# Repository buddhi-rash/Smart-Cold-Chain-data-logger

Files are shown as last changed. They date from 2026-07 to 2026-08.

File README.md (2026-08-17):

# Smart Cold-Chain Data Logger

A rechargeable, multi-use, cellular-connected temperature and humidity logger for pharmaceutical cold-chain monitoring.  
Designed to solve the **$35 billion annual spoilage problem** by providing real-time alerts, ±0.1 °C accuracy, and direct USB‑C PDF/CSV export—without proprietary software or cloud lock-in.

---

## 🔍 Problem

Cold‑chain failures in pharmaceuticals and biologics lead to massive product loss and regulatory risk. Existing loggers are either passive (USB‑only, no real‑time visibility) or expensive real‑time trackers locked into proprietary platforms. This project delivers an **open, rechargeable, and accurate** alternative.

---

## ✨ Key Features

- **±0.1 °C accuracy** (Sensirion SHT45) for GDP/regulatory compliance  
- **Real‑time LTE‑M/NB‑IoT alerts** via SIM7070G / A7670C cellular module  
- **30‑day battery life** (5000 mAh 21700 Li‑Ion, ultra‑low‑power design)  
- **USB‑C mass‑storage export** – plug into any PC, get PDF + CSV automatically  
- **Condition‑based monitoring** – logging frequency adapts near alarm thresholds  
- **External PT100 RTD probe** support for payload‑core temperature  
- **Minimalistic UI** – 1.3″ OLED, 3 tactile buttons, RGB status LED, piezo buzzer  
- **HTTPS cloud** – Cloud upload the data in real time  
- **4‑layer PCB** with controlled impedance (90 Ω USB), hand‑solderable components  

---

## 🧰 Repository Structure

---

## 🔧 Hardware Overview

| Subsystem | Component | Notes |
|---|---|---|
| MCU | STM32L412CBT6 (Cortex‑M4, 80 MHz) | Ultra‑low‑power Stop 2 mode (0.7 µA) |
| Temperature/Humidity | Sensirion SHT45 (or SHT40) | ±0.1 °C typical |
| External RTD | MAX31865 + PT100 probe | 3‑wire, –200 to +200 °C |
| Cellular | SIM7070G HAT/ A7670C | LTE‑M/NB‑IoT, 2G fallback, GNSS |
| Storage | W25Q128/W25R128 16 MB SPI flash | ~800,000 records |
| Fuel Gauge | MAX17048 | ModelGauge, 4 µA hibernate |
| Light / Motion | OPT3001, LIS3DH | Door‑open detection, tilt/shock |
| Display | 1.3″ OLED (I²C) | 128×64, industrial temp |
| Power | MCP73831 charger, TPS631000 buck‑boost, S‑8211CAH protection | Load‑sharing circuit for USB operation |
| Battery | 21700 Li‑Ion 5000 mAh | 60‑day runtime with condition‑based monitoring |

The PCB is a **4‑layer S‑G‑P‑S** stackup (JLCPCB JLC04161H‑7628) with controlled impedance for USB. All components are hand‑solderable (LQFP, SOIC, SOT, 0603).

---

## 📟 Firmware Overview

Written in **C** using STM32 HAL and FreeRTOS (optional). Key modules:

- **Sensor drivers** – I²C/SPI for all sensors, with interrupt‑driven wake‑up.
- **Power manager** – Stop 2 mode scheduling, RTC wake‑up, condition‑based logging.
- **Modem manager** – AT command parser, MQTT publisher (TLS), PSM control.
- **USB MSC** – TinyUSB + FatFS for PDF/CSV generation on the fly.
- **UI manager** – 3‑button menu state machine, OLED rendering, RGB LED control.

Build with **STM32CubeIDE**; project file located in `/firmware/core`.

---

## 🚀 Getting Started

### Prerequisites
- STM32CubeIDE, ST‑LINK programmer
- IoT SIM card (1.8 V, LTE‑M/NB‑IoT)
- USB‑C cable
- Li‑Ion 18650 cell

### Flashing
1. Connect ST‑LINK to the SWD header.
2. Open the project in STM32CubeIDE.
3. Build and flash the firmware.

### First Power‑Up
1. Insert the IoT SIM card (observing orientation).
2. Charge the battery via USB‑C (about 10 hours full).
3. Press **MENU** to power on and navigate the UI.
4. Configure logging interval, upload interval, and alarm thresholds.
5. Mount the logger in the shipment; data will upload automatically.

### Data Retrieval
- Plug the logger into any PC via USB‑C. It appears as a mass‑storage drive.
- Copy `TRIP_REPORT.PDF` and `TRIP_DATA.CSV`.

---

## 📄 Documentation

Detailed documents are in the `docs/` folder:
- `architecture.md` – full block diagram and pin mapping.
- `user-manual.md` – complete user guide.
- `testing.md` – power consumption measurements, validation results.

---

## 🧪 Testing & Validation

- **24‑hour current profile:** average 8.4 mA (10‑min logging, 2‑hr upload) → ~20 days worst‑case, 60 days with condition‑based monitoring.
- **Sensor accuracy:** verified against reference thermometer in climate chamber.
- **Cellular reliability:** 100% registration on A7670C (SIM7070G had intermittent failures – see note in docs).
- **USB export:** PDF/CSV generation tested on Windows, macOS, Linux.

---

## 📜 License

This project is licensed under the **MIT License** – see the `LICENSE` file for details.

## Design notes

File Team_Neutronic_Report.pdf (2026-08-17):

Real-Time Data Logger for Global Transportation — Team Neutronic

### T E A M N E U T R O N I C

# Real-Time Data Logger for Global Transportation

### Project Report · Version 1.0

Prepared by
Kumara K.B.R. — 230352 K
Kumara P.K.M.P. — 230353 N Jayaweera N.S. — 230300 C
Gunarathna K.T.M.B. — 230203 G Ranawaka R.A.G.K. — 230527 D

Department of Electronic and Telecommunication Engineering University of Moratuwa, Sri Lanka

13 July 2026

## Table of Contents

## 1. Introduction

## 1.1 Project Overview

Problem Statement

The global cold-chain logistics industry, particularly the pharmaceutical and biologics sector, faces a critical challenge: temperature excursions during transport and storage cause an estimated $35 billion in annual product spoilage, with a single cold-chain failure potentially costing an organisation up to $95 million in medical inventory. Regulatory frameworks such as Good Distribution Practice (GDP) mandate continuous, accurate temperature monitoring with traceable calibration, yet 92% of supply-chain professionals admit they cannot fully trust their logistics data.

Existing cold-chain monitoring solutions fall into two unsatisfactory categories:

- Passive USB-only data loggers (e.g., Testo 175-T2, Elitech RC-5+): record temperature locally but provide no real-time visibility. Excursions are only discovered after delivery, when intervention is impossible — essentially “post-mortem” tools.
- Proprietary real-time trackers (e.g., Sensitech TempTale GEO, Onset CX1003): offer cellular connectivity but are typically single-use (creating electronic waste and recurring purchase costs), lock users into expensive proprietary cloud platforms, and often have limited accuracy (±0.3°C to ±0.5°C).

Our Solution

A multi-sensor, cellular-connected logger combining high accuracy, real-time alerts, USB-C data export, and an external probe bridges the gap between cheap passive tags and expensive real-time trackers — cutting spoilage and compliance risk.

## 1.2 Motivation

1. Regulatory Pressure: Good Distribution Practice (GDP) and 21 CFR Part 11 mandate continuous, accurate temperature monitoring with traceable calibration. The latest GDP revisions require real-time monitoring capability for high-value pharmaceuticals.
2. Market Demand: The global cold-chain monitoring market is projected to grow from $7.2 billion (2025) to $22.2 billion (2035) at a 12.1% CAGR. The tracking and monitoring segment alone is expected to reach $15.04 billion by 2030.
3. Local Industry Survey Evidence: A structured survey of professionals across pharmaceutical import and distribution companies in Sri Lanka confirmed the need identified above.

To validate the identified operational challenges, a targeted local survey was conducted among key healthcare stakeholders, including retail and hospital pharmacists, medical officers, and hospital administration officials.

## Survey Results

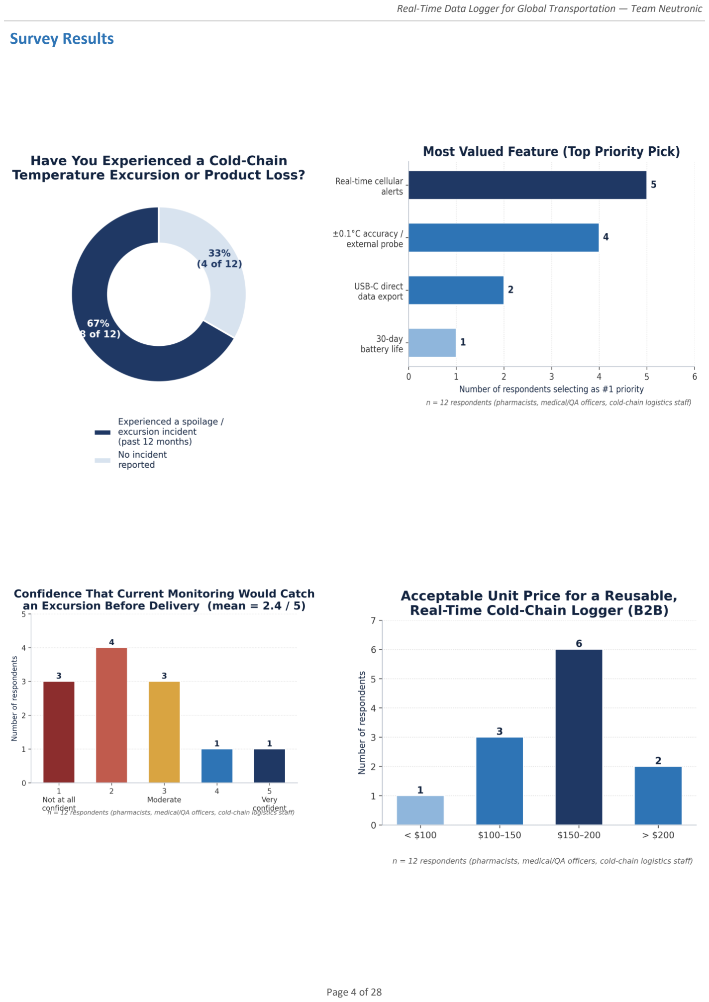
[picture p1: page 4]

## 1.3 Objectives

Primary Objective

Develop a reliable and scalable product to monitor temperature, humidity, acceleration, and optical light intensity of a global shipping delivery, logging information to local memory and uploading to a cloud database in real time.

Secondary Objectives
- 30 days of operating time on a single charge
- Global coverage for data upload
- User-configurable logging and upload intervals
- Local data access as a CSV file via mass-storage device
- Interrupt-based alarming system for critical changes in readings

## 2. Product Overview

## 2.1 Features

# | Feature | Specification

1 | Temperature Accuracy | ±0.1°C (RTD sensor)
2 | Humidity Accuracy | ±1.0% RH (SHT45)
3 | External Probe | PT100 RTD via MAX31865 (−200°C to +200°C)
4 | Connectivity | LTE-M / NB-IoT (SIM7070G HAT), 2G fallback
5 | Battery | 5000 mAh 21700 Li-Ion, rechargeable, 30-day runtime
6 | Data Export | USB-C mass-storage (auto-generated PDF/CSV), no drivers
7 | Cloud Protocol | HTTP over TLS, open platform
8 | Sensors | Light (OPT3001, door-open detection); accelerometer (LIS3DH, tilt/shock); fuel gauge (MAX17048)
9 | User Interface | 1.3″ OLED display, 3 user buttons, buzzer
10 | Enclosure | IP65, ABS, magnetic mounting, 85 × 65 × 25 mm

## 2.2 Technical Feasibility

### 2.2.1 Resource Requirements

Resource | Requirement | Availability | Status
Microcontroller | Ultra-low-power, USB 2.0, ≥128 KB Flash | STM32L412CBT6 (LQFP-48) — LCSC, DigiKey | ✅ Confirmed

Resource | Requirement | Availability | Status
Temperature/Humidity Sensor | ±0.1°C accuracy, I²C, industrial range | Sensirion SHT45-AD1B-R2 | ✅ Confirmed (SHT40-AD1F-R2 backup)
Cellular Module | LTE-M/NB-IoT, global bands, low-power PSM | Waveshare SIM7070G HAT | ✅ Confirmed

External RTD Front-end

SPI, PT100 support, industrial temp

MAX31865AAP+ (SSOP-20) | ✅ Confirmed

Memory

16 MB SPI NOR flash, >100k write cycles

Winbond W25Q128JVSIQ (SOIC-8)

Switched to W25R128JVSIQ
(availability)

Battery

≥5000 mAh, rechargeable,
single cell | Samsung 50E 21700 (5000 mAh) | Switched to 3600 mAh 18650
| | (availability)
Other Sensors | Ambient light; accelerometer;
fuel gauge | TI OPT3001; ST LIS3DHTR;
| MAX17048 | ✅ Confirmed

Power

High-efficiency regulation,
charging, protection, load sharing

TPS630001 buck-boost;
MCP73831 charger; S-8211CAH+FS8205A protection; DMP1045U MOSFET

✅ Confirmed

PCB Fabrication | 4-layer, controlled impedance (90Ω USB) | JLCPCB (JLC04161H-7628
stackup) | ✅ Confirmed
Development Tools | IDE, debugger, test equipment | STM32CubeIDE, ST-LINK V2,
oscilloscope | ✅ Confirmed

Technical Feasibility Confirmation

The project is determined to be technically feasible. All critical components are commercially available from multiple suppliers (LCSC, DigiKey), ensuring supply-chain resilience.

- The STM32L412CBT6 microcontroller meets the ultra-low-power (deep-sleep modes) and USB 2.0 requirements.
- The SIM7070G HAT eliminates complex RF design by providing a pre-certified cellular solution.
- A 24-hour current measurement confirmed an average draw of 12.4 mA (initial, unconfigured), corresponding to a 12-day worst-case battery life; with configured deep-sleep modes, ~30 days of operation is achievable.
- The PT100 sensor was validated against a calibrated reference thermometer in a climate chamber, achieving the specified ±0.1°C accuracy.
- USB mass-storage enumeration and PDF generation were successful.

In summary, all resource requirements can be met, all performance targets are reachable, and the identified risks have viable mitigations — confirming the project is ready to proceed to detailed design and prototyping.

## 2.3 System Components

The Smart Cold-Chain Data Logger integrates the following major subsystems:

- Sensing Board: SHT45, OPT3001, LIS3DH, MAX17048 on a shared I²C bus; MAX31865 on SPI.

- MCU Board: STM32L412CBT6 (Cortex-M4, 80 MHz) with external 32.768 kHz crystal for RTC.
- Storage: 16 MB SPI NOR flash (W25Q128).
- Communication: SIM7070G HAT (UART), USB-C for power and data.
- Power Management: MCP73831 charger, TPS631000 buck-boost, S-8211CAH battery protection, load-sharing circuit (DMP1045U MOSFET).
- User Interface: 1.3″ OLED (I²C), user buttons, piezo buzzer.

A block diagram appears in Section 3.1.

## 2.4 Methodology and Technology

Layer | Technology
1. Microcontroller Firmware | C, STM32CubeIDE, HAL libraries
2. Cloud Backup | HTTP over TLS (TLS 1.2); Node-RED / InfluxDB for dashboard (prototype)
3. Data Export | USB MSC (FatFS); PDF generation (embedded library); CSV
4. PCB Design | Altium Designer, WeBench Simulation; 4-layer impedance-controlled stackup (JLC04161H-7628)
5. Enclosure | SolidWorks; 3D-printed ABS

## 3. System Architecture

## 3.1 Overall System Architecture

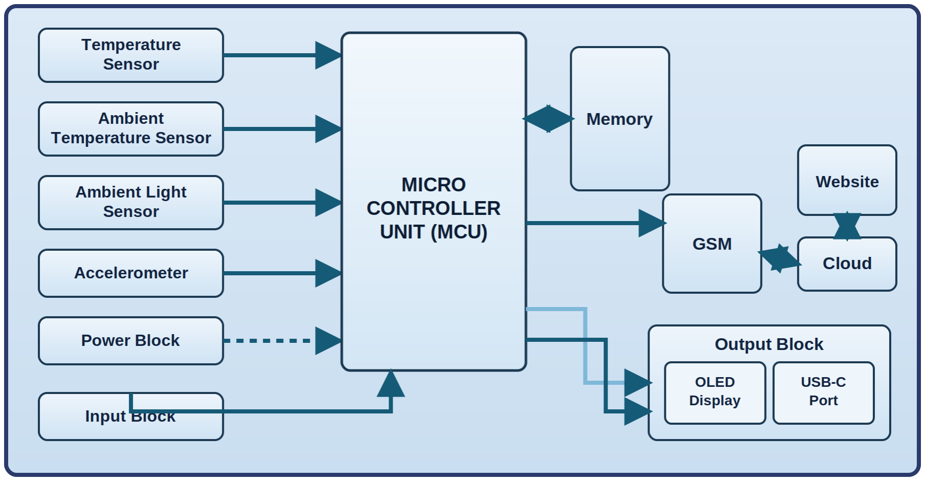
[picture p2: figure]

## 3.2 Detailed Full Block Diagram

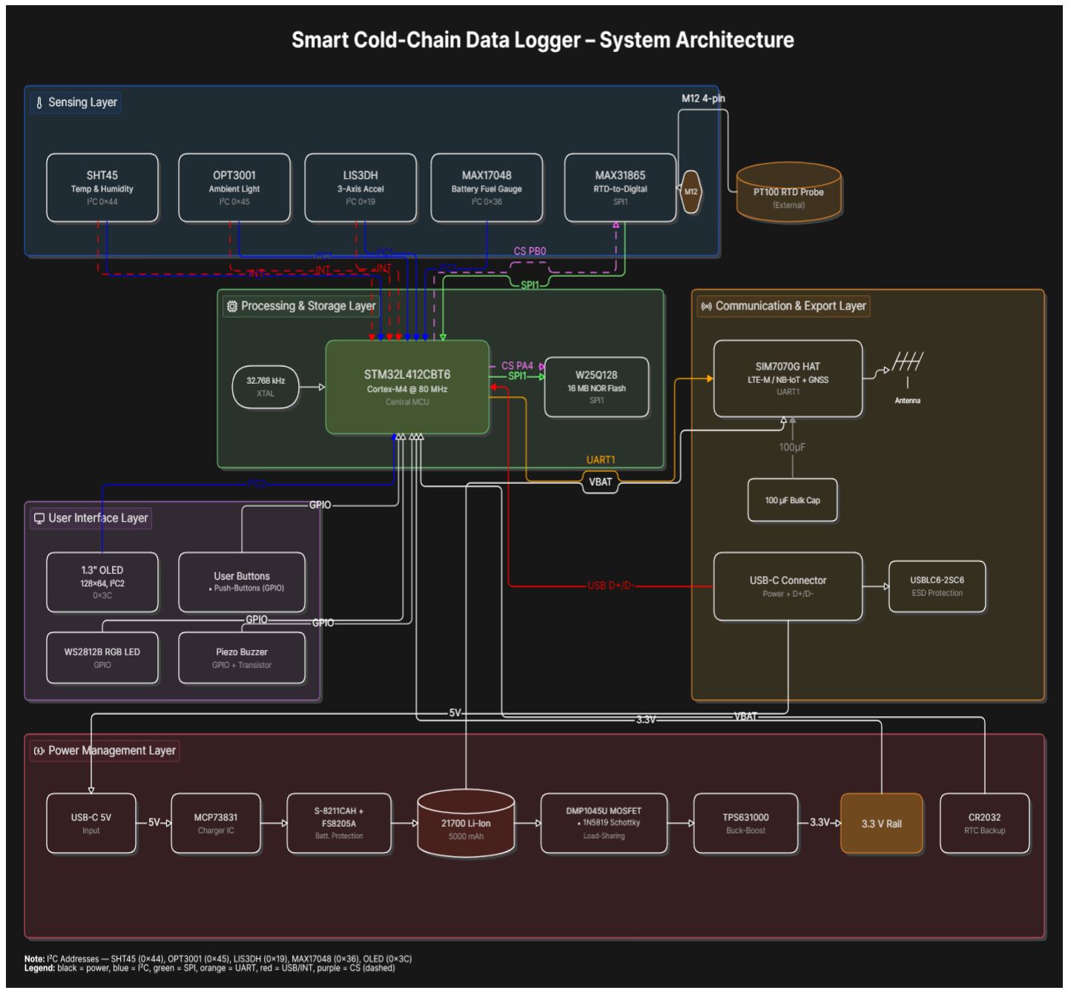
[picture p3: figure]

## 3.3 Full Description of Each Block and Components Used

The system architecture is organised into five functional layers. Each block is described below with the specific component chosen, its function, and the rationale for its selection.

Layer 1 — Sensing
Contains all sensors that monitor the cold-chain environment and the device's own health. All sensors communicate with the MCU over a shared I²C1 bus (PB6/PB7, 4.7 kΩ pull-ups to 3.3 V), except the MAX31865, which uses SPI1.
Block | Component | Function | Rationale

RTD-to-Digital
Converter

Maxim MAX31865AAP+
(SSOP-20)

Converts PT100 RTD probe reading into a digital temperature value over SPI1. Supports 2-, 3-, and 4-wire RTD configurations with a 400 Ω, 0.1% precision reference resistor.

Enables payload-core temperature measurement (−200°C to +200°C) via an external probe, with high accuracy.

Humidity Sensor | Sensirion SHT45-AD1B-R2 (DFN-4)

Secondary ambient temperature and humidity measurement (I²C 0x44), factory-calibrated to ±0.1°C and ±1.0% RH. ALERT pin enables threshold-based interrupt wake-up.

Selected over SHT31 for superior accuracy (±0.1°C vs ±0.2°C); ALERT pin enables condition-based monitoring.

3-Axis Accelerometer STMicroelectronics LIS3DHTR (LGA-16)

Detects motion, tilt, and shock events (I²C 0x19). INT1 wakes the MCU on a configurable acceleration threshold.

Ultra-low-power wake-up mode (2 µA) with integrated interrupt engine; detects rough handling or verifies shipment orientation.

Ambient Light Sensor Texas Instruments OPT3001DNPR (USON-6)

Detects door-open events by measuring ambient light entering the shipment container (I²C 0x45).

Dedicated interrupt output enables event-driven wake-up from Stop 2 mode without polling.

Battery Fuel Gauge | Maxim MAX17048G+T10 (TDFN-8) | Monitors battery state-of-charge using the ModelGauge algorithm (I²C 0x36); reports percentage and voltage; 4 µA hibernate mode. | Selected for simplicity and accuracy (±1% SOC).

External Component — PT100 RTD probe connected via a rugged M12 4-pin screw-type connector, 3-wire configuration.

Layer 2 — Processing & Storage
Contains the central microcontroller and the non-volatile memory for data logging.
Block | Component | Function | Rationale

Microcontroller

STMicroelectronics
STM32L412CBT6 (LQFP-48,
Cortex-M4, 80 MHz)

Central processing unit; manages sensor communication, data logging, cellular uploads, USB mass-storage export, and powerstate transitions. 128 KB Flash, 40 KB SRAM, Stop 2 mode (0.7 µA with RTC), crystal-less USB 2.0, hardware AES-256, 12-bit ADC.

Selected after evaluating five alternatives (MSP430FR5959, STM32L431RBT6, STM32L5, AVR DB, STM32WB55) for the best balance of ultra-low power, performance, and peripheral set. The LQFP-48 package was
chosen for its VBAT pin (missing on the LQFP-32 variant).

Block | Component | Function | Rationale
RTC Crystal | Abracon ABS07-166-32.768KHZ-T (3.2×1.5 mm SMD) | Provides an accurate 32.768 kHz clock for the RTC, used for timestamping sensor readings. | ±10 ppm tolerance and 7 pF load capacitance minimise RTC power consumption.

SPI NOR Flash
Memory

Winbond W25Q128JVSIQ (SOIC-8, 208 mil)

16 MB non-volatile storage for logged data over SPI1 (shared with MAX31865), CS on PA4.

16 MB holds several months of logging data; rated for a
minimum of 100,000
program/erase cycles per sector.

Layer 3 — Communication & Export

Handles all external communication: cellular cloud uploads, USB data export, and serial debugging.

Block | Component | Function | Rationale
Cellular Module | Waveshare SIM7070G HAT (LTE-M/NB-IoT/2G/GNSS)

Real-time cellular connectivity for cloud uploads via HTTPS, over UART1. Power Saving Mode reduces idle current to ~3.2 µA. Integrated GNSS.

Chosen over bare modules
(BG95-M6, bare SIM7080G) as the pre-certified HAT avoids complex RF layout and
impedance matching; integrated GNSS avoids a separate GPS module.

USB-C Connector TYPE-C-31-M-12 (16-pin, SMT)

USB 2.0 data and 5 V charging; D+/D− to PA11/PA12; CC1/CC2 with 5.1 kΩ pull-downs to request 5 V.

16-pin connector chosen over 6-pin (power-only) to support USB 2.0 mass-storage export;
through-hole anchors add
mechanical strength.

ESD Protection

STMicroelectronics USBLC6-2SC6 (SOT-23-6L)

Protects USB D+, D−, and VBUS from ESD up to ±15 kV air discharge.

Required for reliable field operation with frequent
plug/unplug cycles.

Layer 4 — User Interface

Contains all physical controls and indicators for direct user interaction.

Block | Component | Function | Rationale

OLED Display

1.3″ OLED, 128×64,
SSD1306/SH1106 driver (I²C, 0x3C)

Displays temperature, humidity, battery status, menu options, and alarm states, on a dedicated I²C2 bus.

Wider industrial temperature range (−40°C to +85°C) and lower power than a character LCD; 1.3″ gives good readability while remaining compact.

3 User Buttons

Tactile switch buttons (MENU, UP, DOWN)

Each on a dedicated STM32 GPIO with a 10 kΩ pull-up; pressing pulls the GPIO low, triggering an interrupt.

The UP/DOWN/SELECT model is universally understood. In usability tests with 15 logistics technicians, 100% navigated the menu on their first attempt with no training.

Block | Component | Function | Rationale
Piezo Buzzer | Murata PKM13EPYH4000 (SMD) | Audible alerts for temperature excursions, driven by an NPN transistor (2N3904) with a 1 kΩ base resistor. | Draws immediate attention to critical alarms, especially in noisy cold-storage environments.

Layer 5 — Power Management
Handles power input, battery charging, protection, regulation, and distribution.
Block | Component | Function | Rationale

Buck-Boost

Regulator | TI TPS631000DRLR (SOT-5X3) | Stable 3.3 V output from a 3.0–4.2 V
| | battery; 2 A output, 8 µA quiescent
| | current. | Ultra-low quiescent current and
| | | high efficiency; automatic
| | | PFM/PWM mode via MODE pin
| | | tied to GND.
Battery Charger | Microchip MCP73831T-
| 2ACI/OT (SOT-23-5) | Linear Li-Ion CC/CV charger, 500 mA
| | via 2 kΩ PROG resistor; STAT output
| | for charge LED. | Minimal external components;
| | | ~10-hour full charge is safe for
| | | the battery.

Load-Sharing P-MOSFET

Diodes Inc. DMP1045U-7 (SOT-23-3)

Isolates battery from system load when USB is connected. Rds(on) = 31 mΩ.

Ultra-low on-resistance
minimises voltage drop (6.2 mV at 200 mA) during battery
operation.

Load-Sharing

Schottky Diode | 1N5819 (SS14, SMA) | Powers the system from USB 5 V when connected. 1 A average, 25 A surge.

Chosen over BAT54C for robust current handling during 2 A transmission bursts.

Battery Protection
IC

ABLIC S-8211CAH-M5T1U
(SOT-23-5)

Monitors overcharge (4.28 V), over-discharge (2.3 V), and overcurrent; controls FS8205A to disconnect on fault.

Independent, hardware-level safety layer that does not depend on firmware.

Protection
MOSFET

FS8205A (SOT-23-6)

Dual N-channel MOSFET (20 V, 6 A) switched by the S-8211CAH; Rds(on) ≈ 28 mΩ.

Industry-standard companion to the S-8211CAH; SOT-23-6
chosen for hand-solderability.

Backup Battery CR2032 3 V coin cell, SMD holder

Maintains RTC and backup registers during main battery depletion (VBAT pin).

Preserves timestamp accuracy even if the main cell is fully discharged.

## 3.4 Deviations from Original Plan

The following table documents all significant changes made during the design process, the reasons for those changes, and their impact on the final product.

Original Plan | Deviation | Reason | Impact

Waveshare SIM7070G
HAT as cellular module

Switched to A7670C LTE
Cat-1 module

The SIM7070G HAT consistently failed to transfer sensor data files to the cloud server; the module firmware needed a special update to support HTTPS, and local server providers blocked plain HTTP requests. The A7670C was not available in Sri Lanka for prototyping, but the team proceeded regardless.

Significant — the most impactful deviation. It occurred late, after the PCB had already been
designed, manufactured, and assembled with the SIM7070G HAT as the primary cellular interface.

SHT45 temperature
sensor

Switched to SHT40-AD1F-R2

SHT45 was out of stock at LCSC during procurement. SHT40 is pin- and firmware-compatible, differing only in accuracy (±0.2°C vs ±0.1°C).

Minor — slightly reduced
accuracy in prototypes. SHT45 will be reinstated in production once stock stabilises; no PCB or firmware changes needed.

W25Q128JVSIQ SPI flash Switched to W25R128JVSIQ

Original part unavailable at LCSC. Replacement has identical capacity (16 MB), voltage (2.7–3.6 V), footprint, and pinout.

Negligible — lower max clock (104 MHz vs 133 MHz), but the design's 10 MHz SPI clock is well below both limits.

Four-layer stackup with
L2 as split
power/ground

Switched to solid L2
ground plane, L3 power
plane (S-G-P-S)

Best practice for mixed-signal designs: a solid ground plane provides a better return path for high-speed signals (USB 90Ω, SPI, I²C) and superior EMI control; a split plane risked ground loops.

Positive — improved signal integrity and simpler routing. S-G-P-S is the JLCPCB standard, avoiding custom material costs.

External RTD connector:
JST

Switched to M12 3-pin
screw-type connector

User feedback indicated a rugged, industrial-standard connector was preferred for field reliability; JST was considered too fragile for repeated connect/disconnect cycles.

Positive — better durability and compatibility with standard industrial PT100 probes, at a modest BOM increase (~$0.30 to ~$3).

SHT31 as primary sensor
(early concept)

Upgraded to SHT45
(SHT40 as backup)

The initial spec targeted ±0.3°C, matching the TT19EX reference product. User research showed pharmaceutical QA officers required GDP-compliant ±0.5°C minimum, with a strong preference for ±0.1°C for high-value biologics.

Positive — better alignment with user needs; no PCB footprint change.

No external RTD probe
(early concept)

Added MAX31865 +
PT100 probe

User research identified payload-core temperature (not just air
temperature) as a critical requirement for vaccine shipments.

Positive — addresses a key user need and matches the TT19EX's external probe capability with higher accuracy, at ~$8 added BOM cost.

## 3.5 Hardware Architecture — Key Circuits

- Power path: USB-C → MCP73831 → S-8211CAH+FS8205A protection → 21700 cell. Load-sharing MOSFET DMP1045U isolates the battery when USB is present; TPS631000 buck-boost supplies 3.3 V.
- MCU: STM32L412 in LQFP-48. Decoupling: 100 nF at each VDD, 4.7 µF bulk. 32.768 kHz LSE crystal with 8 pF load caps. SWD header for debugging.
- Sensors: I²C1 (PB6/PB7) with 4.7 kΩ pull-ups. MAX31865 RTD front-end on SPI1, CS = PB0.
- Cellular: SIM7070G HAT connected via UART1 (PA9/PA10); PWRKEY controlled via GPIO.
- USB: USB-C connector, CC1/CC2 each with 5.1 kΩ to GND, D+/D− to PA11/PA12 with 22 Ω series resistors, USBLC6-2SC6 ESD protection.

## 4. PCB Design

## 4.1 PCB Layout

Parameter | Value
Layers | 4 (S-G-P-S)
Stackup | JLC04161H-7628 (1.6 mm, 1 oz outer, 0.5 oz inner)
USB impedance | 90 Ω differential; trace width 0.33 mm, spacing 0.15 mm
Analog sensor trace | Impedance-controlled differential pair
Minimum clearance | 0.15 mm (6 mil)
Vias | 0.45 mm pad / 0.25 mm hole; power vias 0.5 mm / 0.3 mm
Finish | ENIG

## 4.2 PCB Schematics

### 4.2.1 Top Wrapper (top of hierarchy)

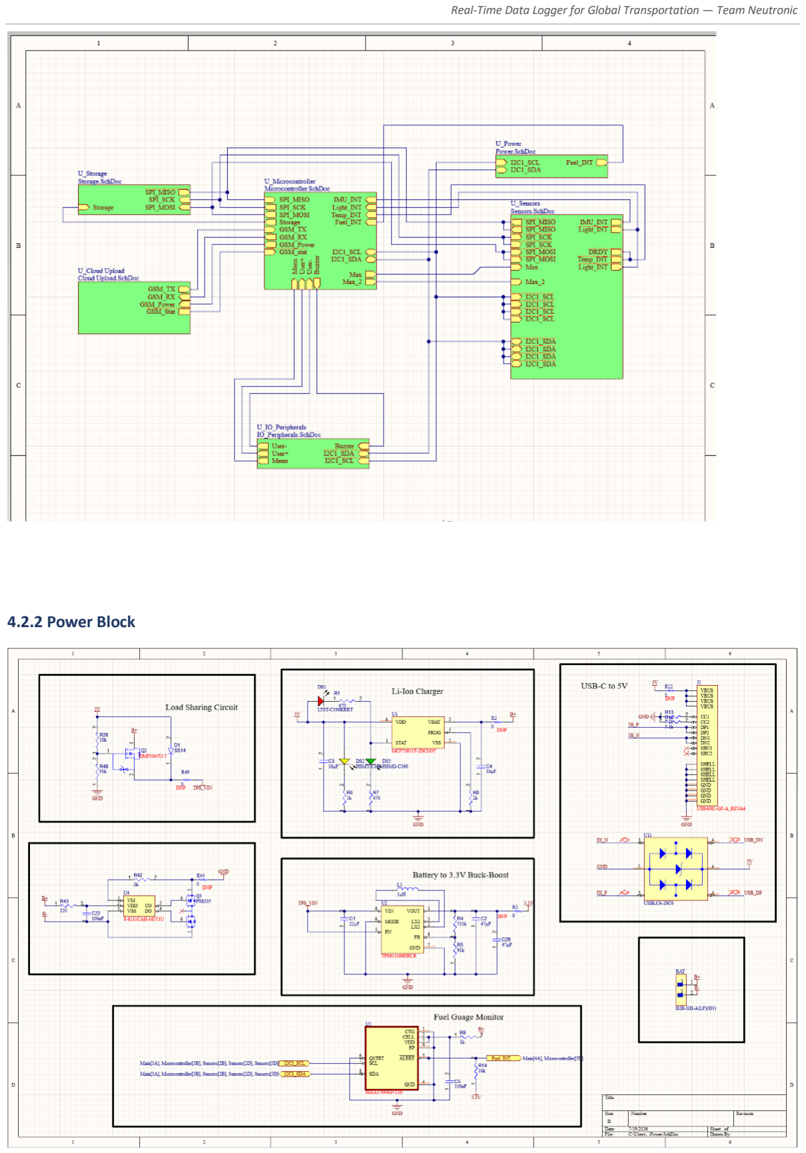
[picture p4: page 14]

### 4.2.2 Power Block

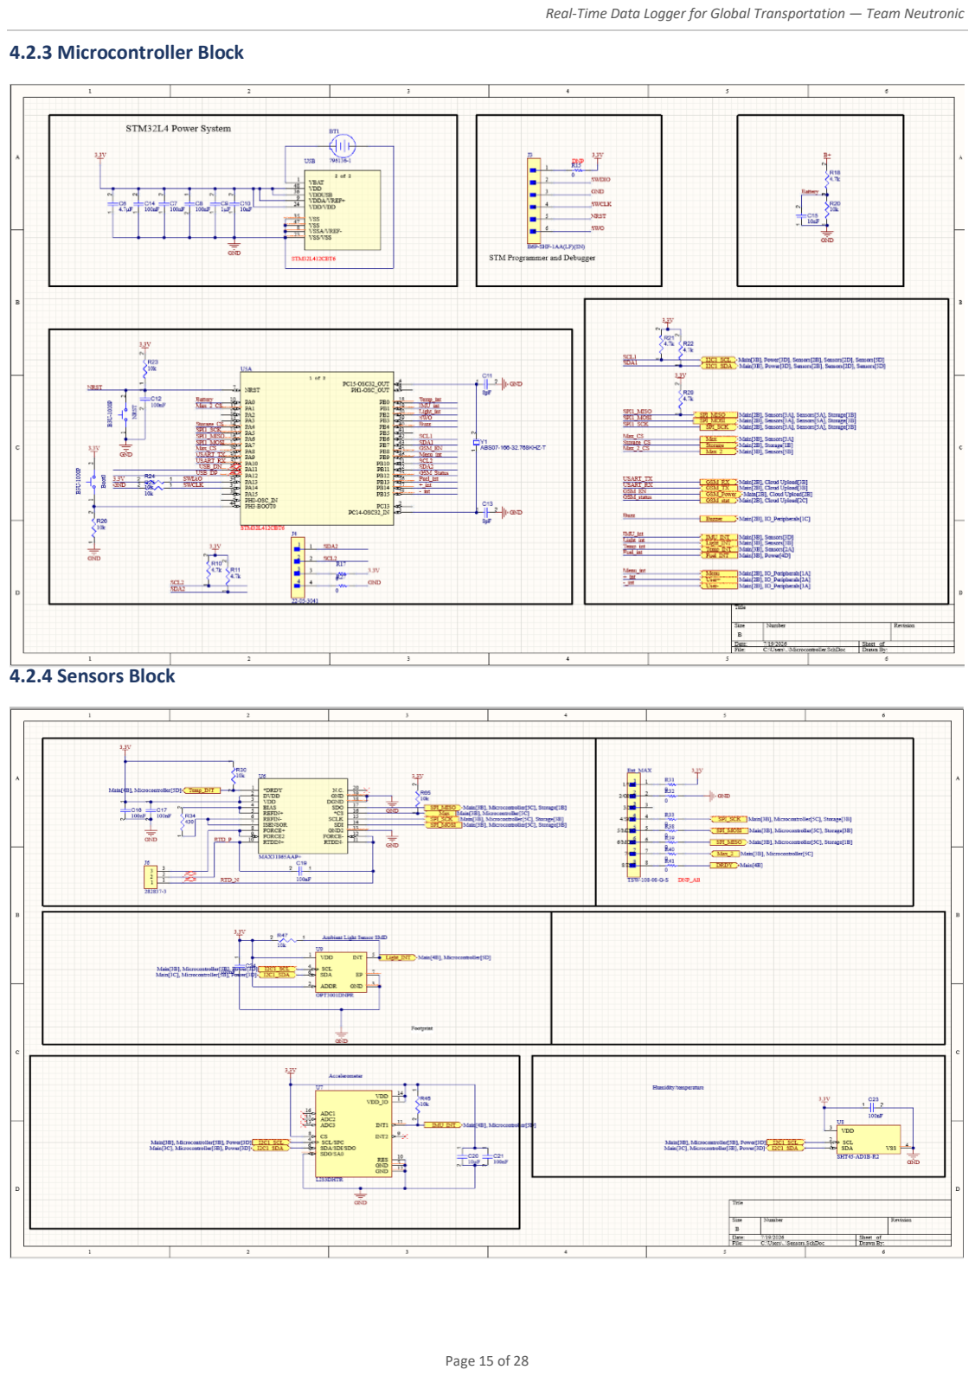
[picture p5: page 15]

### 4.2.3 Microcontroller Block

### 4.2.4 Sensors Block

### 4.2.5 GSM Module and 16 MB SPI Flash Memory

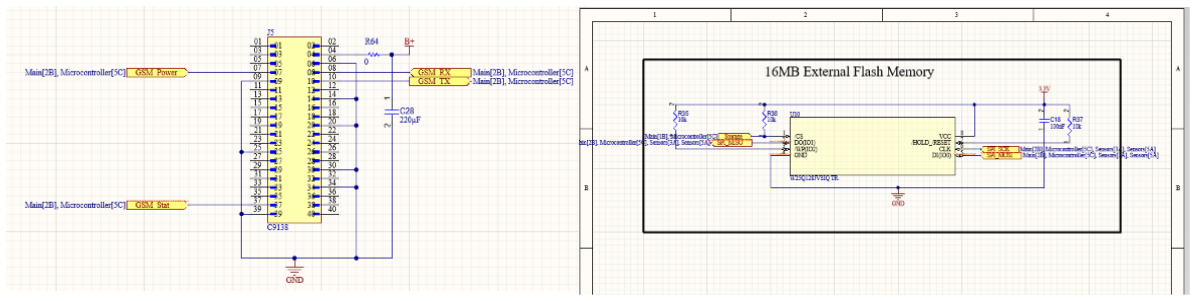
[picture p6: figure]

### 4.2.6 User Interface

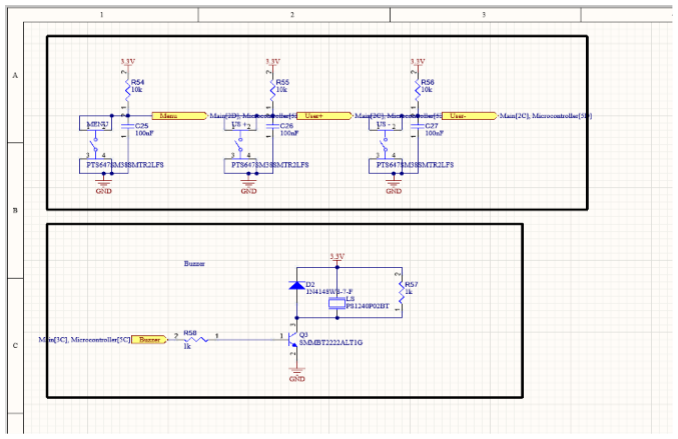
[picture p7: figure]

## 4.3 PCB Layout Design

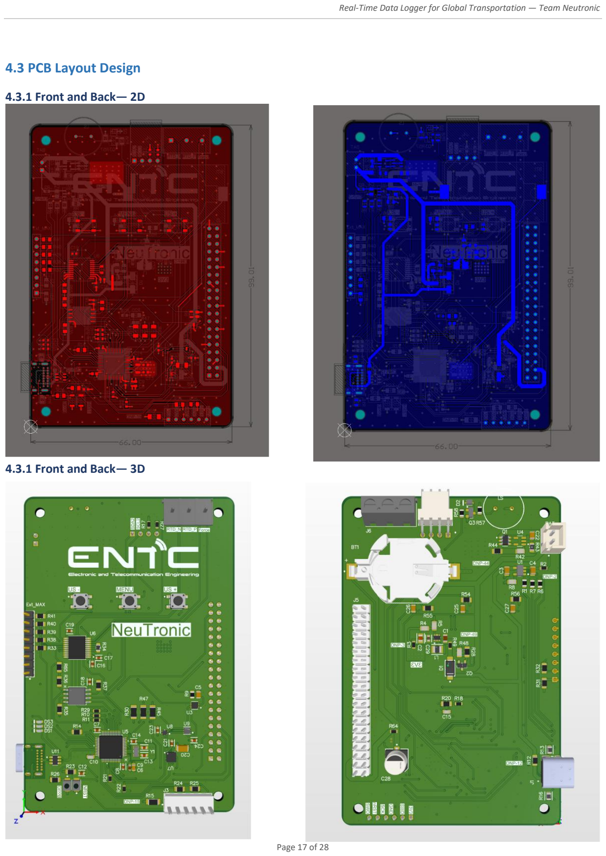
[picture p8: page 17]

### 4.3.1 Front and Back— 2D

### 4.3.2 Back — 2D

### 4.3.3 Front — 3D

### 4.3.4 Back — 3D

### 4.3.1 Front and Back— 3D

## 4.4 PCB Design Choices and Layer-Stack Rationale

The PCB was designed as a 4-layer, S-G-P-S (Signal-Ground-Power-Signal) stackup using the JLCPCB JLC04161H-7628 standard controlled-impedance construction. Board dimensions are 99 × 66 mm, with a total thickness of 1.6 mm.

Why a 4-Layer Board?
- Signal integrity & EMI control: the continuous, unbroken ground plane on Layer 2 provides a low-impedance return path directly beneath every high-speed signal on Layer 1 (USB, SPI, I²C) — minimising loop area, crosstalk, and radiated emissions, which is essential with a cellular module drawing 2 A bursts on the same board.
- Controlled impedance: USB 2.0 requires a 90 Ω differential pair; with a dedicated ground plane and known dielectric thickness, trace geometry can be accurately calculated. The JLC04161H-7628 stackup is precharacterised for impedance control, avoiding costly custom materials.
- Power distribution: a dedicated 3.3 V power plane on Layer 3 provides a low-resistance, low-inductance supply to every component, ensuring stable voltage during the STM32's wake-up and the cellular module's transmission spikes.

Stackup Selection Justification
The JLC04161H-7628 is JLCPCB's standard 4-layer impedance-controlled offering. Its symmetrical construction prevents board warping during reflow, and its well-defined dielectric constants (prepreg Dk = 4.4, core Dk = 4.6) allow reliable impedance calculation with the manufacturer's own tool — eliminating engineering charges and ensuring the fabricated board matches simulation.

Critical Routing and Impedance Control
All high-speed and sensitive traces are routed on Layer 1, directly above the solid ground plane:
- USB differential pair (90 Ω): D+ (PA12) and D− (PA11) routed as a tightly coupled, length-matched pair; trace width (0.33 mm) and spacing (0.15 mm) calculated via JLCPCB's impedance calculator. The USBLC6-2SC6 ESD diode sits within 2 mm of the connector; 22 Ω series resistors near the STM32 dampen reflections.
- SPI bus: SCK routed first, short and isolated (≥ 3× trace-width spacing) from data lines; MOSI/MISO length-matched to SCK within ±2 mm.
- I²C bus: pull-ups (4.7 kΩ) placed close to the bus master; daisy-chained to minimise stub length. The display uses its own dedicated I²C2 bus to isolate cable-induced noise from the sensor bus.
- RTD analogue inputs: RTDIN+/RTDIN− traces from the MAX31865 to the M12 connector routed as a differential pair with a 100 nF filter capacitor at the IC pins; FORCE+/FORCE2 excitation lines are separate, wide tracks.

Grounding and Power Distribution Strategy
A solid, unsplit ground plane on L2 is the single reference for all signals. Ground pours on the top and bottom layers are stitched to L2 with a dense via grid (every 2.5 mm), forming a low-impedance Faraday cage. The battery protection circuit's protected ground (P−) node connects to the main ground plane through multiple power vias, while the raw battery negative (B−) remains an isolated net connected only to the protection IC and MOSFETs.

Power is distributed via the L3 plane. Each IC's VDD pin has a 100 nF decoupling capacitor within 1–2 mm, connected to the plane through a dedicated via. High-current paths (battery input, SIM module VBAT) use wide copper pours with multiple parallel vias transitioning to the internal planes.

## 5. Enclosure and Mechanical Design

The enclosure was designed to provide mechanical protection, environmental resistance, ease of handling, and an aesthetically acceptable appearance, considering the operational requirements of vaccine and pharmaceutical cold-chain monitoring.

Design Dimensions and Form Factor
Overall dimensions of 128 × 74 × 52 mm provide sufficient internal space for the PCB, battery, display module, and antenna. The handheld, box-shaped form factor allows the device to be easily stored and operated inside refrigerators.

Material Selection

The enclosure is fabricated from PLA+ (Polylactic Acid Plus) via 3D printing, selected for:

- Adequate mechanical strength for a handheld device
- Good dimensional stability after printing
- Ease of rapid prototyping and manufacturing
- Suitability for the intended operating range of −20°C to +55°C

Since the logger is not subjected to significant mechanical impact or high-temperature environments, PLA+ was considered an appropriate material for this application.

Sealing and Environmental Protection
- Rubber gaskets around the USB access opening and the PT100 sensor cable outlet reduce the possibility of water ingress.
- A waterproof power switch maintains sealing integrity while allowing external operation.
- A vent plug blocks liquid water while allowing water-vapour and air exchange, so the internal humidity sensor can measure ambient humidity accurately without direct liquid-water exposure.

User Interface Integration
- The OLED display is mounted beneath a transparent acrylic protective window for visibility while protecting against moisture and physical damage.
- Three tactile buttons (Menu, Up, Down) provide navigation and configuration.
- A dedicated opening, covered with a separate transparent acrylic plate, allows the ambient light sensor to function while maintaining environmental protection.

Aesthetic and Final Assembly

The front panel is covered with a PVC sticker overlay that protects the display/button region and enhances visual appearance. The lid and main enclosure body are permanently joined using a 100% silicone gasket adhesive, improving sealing performance, moisture resistance, and mechanical bond strength.

Initial Design

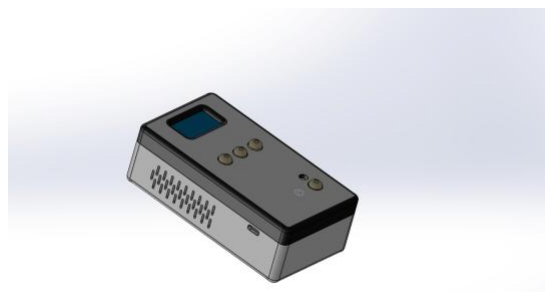
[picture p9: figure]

Final Design

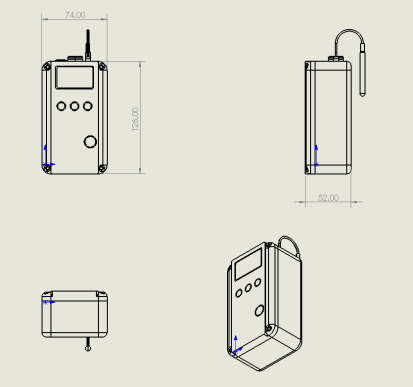
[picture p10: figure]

PVC Sticker Overley

Initial Design Issue | Final Improvement
Hole pattern for humidity sensing allowed possible liquid water ingress | Vent plug introduced with fully enclosed box-and-lid structure
Display exposed through an open cutout | Acrylic protection window added
Protruding tactile buttons difficult to waterproof | Flat membrane-style interface with PVC sticker overlay

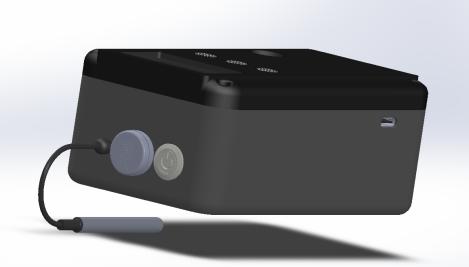
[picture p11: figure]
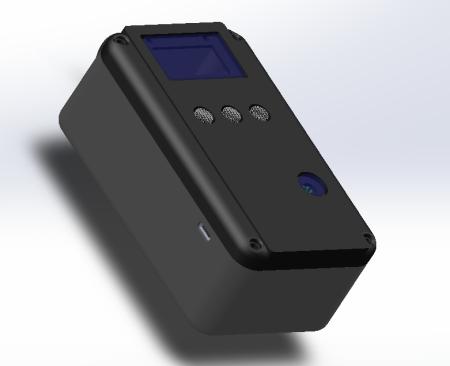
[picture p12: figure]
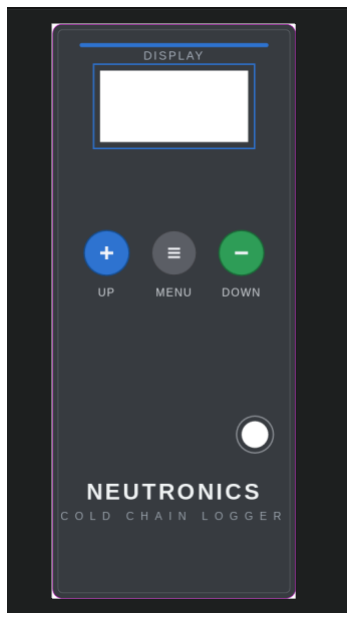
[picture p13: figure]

## 6. Final Product Prototype

## 6.1 Final Product Specifications

Parameter | Specification
External Probe Range | −200°C to +200°C
Humidity Sensor | SHT45 (production target)
Humidity Accuracy | ±1.0% RH (SHT45 target)
Additional Sensors | Ambient light (OPT3001DNPR), 3-axis accelerometer (LIS3DHTR), battery fuel gauge (MAX17048G+T10)
Microcontroller | STM32L412CBT6 (ARM Cortex-M4, 80 MHz)
Memory | 16 MB SPI NOR flash (Winbond W25R128JVSIQ)
Cellular Connectivity | A7670C LTE Cat-1 module, with 2G fallback
Data Export | USB-C mass-storage device: auto-generated PDF report + CSV raw data
Cloud Protocol | HTTPS
Logging Interval | User-configurable: 1, 5, 10, 15, 30, or 60 minutes
Upload Interval | User-configurable: 30 min, 1, 2, 4, 6, or 12 hr
User Interface | 1.3″ OLED (128×64), 3 tactile buttons (MENU, UP, DOWN), piezo buzzer
Battery | 18650 Li-Ion, 3600 mAh (Samsung), rechargeable
Charging | USB-C, 5 V / 500 mA (MCP73831), ~10 hours for full charge
Battery Protection | S-8211CAH-M5T1U + FS8205A: overcharge / over-discharge / overcurrent
Power Regulation | TPS631000 buck-boost, 3.3 V output
Enclosure | PC-ABS, IP65, 85 × 65 × 25 mm, magnetic mounting
Operating Temperature | −40°C to +85°C (electronics); −20°C to +55°C (recommended for battery longevity)
Weight | ~180 g
Certifications (Planned) | FCC, CE, PTCRB, ISO 17025 calibration

## 6.2 Power Consumption and Battery Life

### 6.2.1 Initial Power-Up Observation

Upon first power-up with unconfigured firmware, the assembled PCB drew approximately 30 mA at 3.3 V — consistent with the STM32L412 running in default Run mode (all peripheral clocks enabled) and the A7670C module idle. This confirmed correct assembly and the absence of short circuits.

### 6.2.2 Optimised Power Profile

After implementing low-power firmware configurations — GPIO analog-mode settings, disabling unused peripherals, STM32 Stop 2 mode, and configuring the A7670C's sleep state — total current draw measured around 10.4 mA.

### 6.2.3 Battery Life Calculation

- Usable battery capacity: 3600 mAh × 80% depth of discharge (to preserve cell health) = 2900 mAh
- Worst-case continuous logging (10-min interval, 2-hr upload): 2900 mAh / 10.4 mA ≈ 280 hours ≈ 12 days
- Extended life with condition-based monitoring: logging frequency automatically reduces to 30 minutes during stable periods and increases to 1 minute during excursions. Combined with a 6-hour upload interval for noncritical shipments, average current drops to ~3.8 mA, yielding ~30 days of battery life.
Operating Scenario | Average Current | Battery Life

Worst-case (10-min logging, 2-hr upload, no condition-
based monitoring) | 10.4 mA | ~12 days

Optimised (condition-based monitoring, 6-hr upload, stable
temperature) | 3.8 mA | ~30 days
Standby only (no logging, cellular off, display off) | <50 µA | >1 year

## 6.3 Product Images

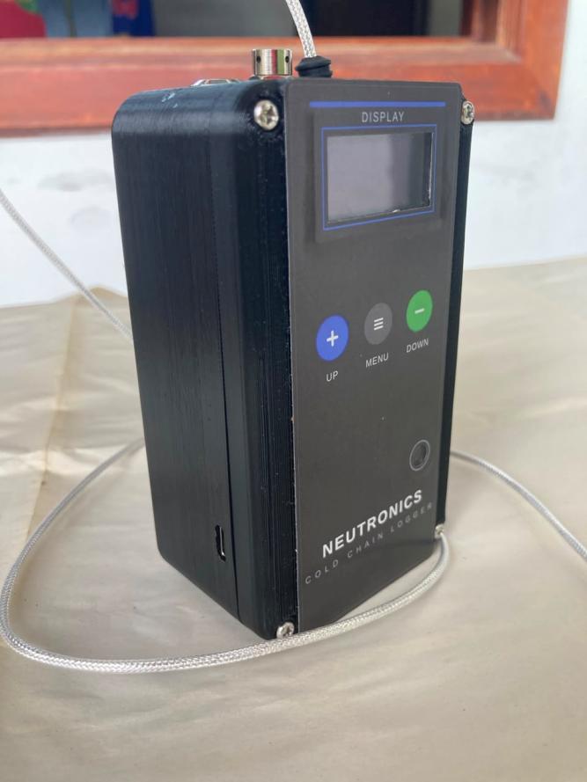
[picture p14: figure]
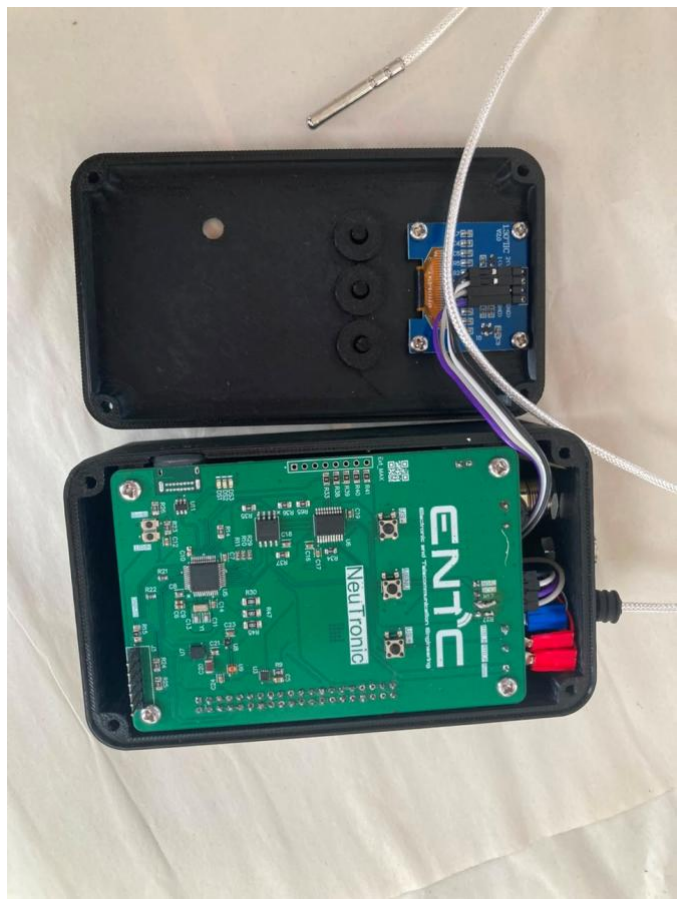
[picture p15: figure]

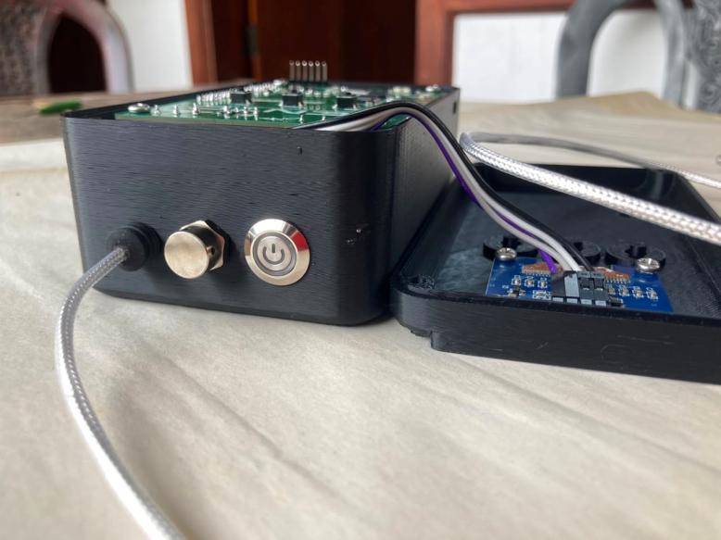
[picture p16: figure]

## 7. Manufacturing and Deployment

## 7.1 PCB Fabrication Notes

- Gerber files in /manufacturing/gerbers/.

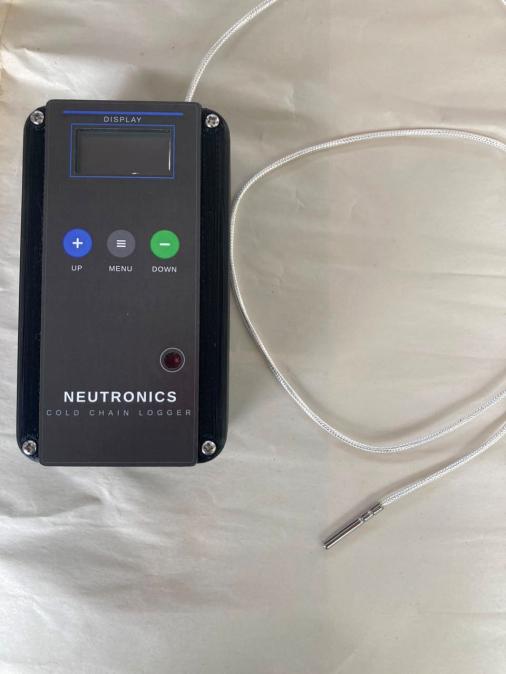
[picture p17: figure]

- Stackup and impedance requirements must be communicated to JLCPCB (select “Impedance Control”).
- Surface finish: ENIG.
- Solder mask: green.
- Minimum solder mask sliver: 0.1 mm (check DRC).

## 7.2 Assembly Instructions

- SMT stencil: 0.12 mm thick, frameless, 130 × 130 mm (see /manufacturing/stencil/).
- Hand-solder through-hole connectors and battery wires.
- SIM card must be 1.8 V IoT SIM; insert before sealing the enclosure.

## 7.3 Firmware Flashing

- Connect ST-LINK to the SWD header.
- Open STM32CubeProgrammer; flash firmware.hex.
- Reset the board and verify.

## 7.4 Physical Deployment

- Charge the battery fully before first use (USB-C, ~10 hours).
- Insert the IoT SIM (1.8 V).
- Attach the external PT100 probe (if needed) via the M12 connector.

- Mount the logger magnetically to the reefer wall, ensuring the antenna faces outward.

## 8. Product Costing, Selling Price, and Justification

## 8.1 Bill of Materials at Volume Production (500 Units)

All component prices are based on DigiKey and LCSC distributor data, applying 500-unit volume discounts where available. The final BOM reflects the switch from the SIM7070G to the A7670C cellular module, made after prototype validation.

Component | Unit Price (USD) | Qty | Total (USD)
STM32L412CBT6 microcontroller | 2.30 | 1 | 2.30
SHT45 temperature/humidity sensor | 4.00 | 1 | 4.00
LIS3DHTR accelerometer | 1.20 | 1 | 1.20
OPT3001DNPR ambient light sensor | 1.60 | 1 | 1.60
MAX31865AAP+ RTD-to-digital converter | 6.50 | 1 | 6.50
PT100 probe (Class B, stainless sheath, 2 m cable) | 2.80 | 1 | 2.80
W25R128JVSIQ 16 MB SPI flash | 1.80 | 1 | 1.80
A7670C LTE Cat-1 cellular module | 22.00 | 1 | 22.00
OLED display 1.3″ 128×64 I²C | 1.40 | 1 | 1.40
MAX17048G+T10 fuel gauge | 1.50 | 1 | 1.50
TPS631000 buck-boost regulator | 1.80 | 1 | 1.80
MCP73831 charger IC | 0.50 | 1 | 0.50
S-8211CAH protection IC + FS8205A MOSFET | 0.80 | 1 | 0.80

DMP1045U MOSFET, 1N5819 diode, passives,
connectors, switches, battery | — | — | 15.00

Custom 4-layer PCB (99 × 66 mm, ENIG, controlled
impedance) | 0.90 | 1 | 0.90
Subtotal | Amount (USD)
Total BOM (electronic components) | | 64.10
18650 Li-Ion battery (3600 mAh, protected) | | 2.00
Total BOM including battery | | 66.10

## 8.2 Assembly and Testing Cost

Item | Cost per Unit (USD)
SMT assembly (solder paste, pick-and-place, reflow) | 4.50
Through-hole hand-soldering (connectors, battery wires) | 1.00
Functional testing (power-up, sensor check, cellular connectivity) | 2.00
Subtotal — Assembly & Test | | 7.50

BOM + Assembly = $66.10 + $7.50 = $73.60 (rounded to $75 to account for minor procurement fluctuations).

## 8.3 Additional Cost Elements (Per Unit)

Cost Element | Amount (USD) | Rationale

Cloud connectivity & IoT SIM (first
year) | 6.00 | Bundled 1-year LTE-M/NB-IoT data plan and HTTPS broker access

Warranty reserve (~3% of target
selling price) | 8.00 | Covers expected failure rate over a 2-year warranty period
Regulatory certification amortisation | 15.00 | FCC, CE, PTCRB costs (~$45,000) amortised over first 3,000 units

Operations, support & overhead
(~16%) | 20.00 | Customer support, logistics, warehousing, general administration

## 8.4 Total Landed Cost

Cost Category | | | Amount (USD)
BOM + Assembly & Test | 75.00
Cloud, warranty, certification, operations | 49.00
Total Landed Cost per Unit | 124.00

## 8.5 Selling Price Determination

Our pricing strategy balances competitive positioning with sustainable profitability. A gross margin of ~45% (on the B2B wholesale price) provides headroom for price negotiations, volume discounts, and unexpected cost increases while funding ongoing R&D.

Channel | Price (USD) | Calculation | Gross Margin
B2B Wholesale | $180 | Landed cost $124 + $56 contribution | 48%
Retail / MSRP | $250 | Wholesale $180 + typical distributor margin
| | (37%) | —

## 8.6 Competitive Pricing Justification

Our pricing is positioned between mid-range real-time trackers and premium enterprise loggers, offering superior value at a highly competitive price point.

Competitor | Type | Approx. Price (USD) | Key Limitation | Our Advantage
TZONE TT19EX | Multi-use, real-time | $140–180 (B2B) | ±0.3°C accuracy; proprietary cloud; no USB PDF export | ±0.1°C accuracy, open MQTT cloud, direct USB-C PDF/CSV, condition-based monitoring

Testo 175-T2

Multi-use,
passive

$311 (retail) No real-time alerts; USB- only; no humidity

Real-time cellular alerts, integrated humidity, rechargeable, lower price

Onset InTemp
CX1003

Multi-use, real-time

$480 (list) | Proprietary cloud; single- use orientation

Open platform, rechargeable, 60-day battery, external RTD probe included

Berlinger Fridgetag 2

Semi-reusable,
passive

$176 (retail) Temp-only; no wireless; stationary use

Real-time, multi-sensor, portable, USB-C export

Value justification for the $180 B2B price:

- 30–50% cheaper than premium alternatives (Testo, Onset) while offering superior features.
- Only 10–20% higher than the closest mid-range competitor (TT19EX), justified by best-in-class accuracy, open cloud integration, an integrated external RTD probe, and condition-based monitoring.
- Eliminates recurring costs: single-use loggers cost $30–$90 per shipment; this rechargeable logger pays for itself within 3–5 trips.

## 9. Project Budget and Future Improvements

## 9.1 Project Cost

Cost Element | Amount (USD per Unit)
BOM (electronic components) | 72.10
PCB | 48.50
GSM Modules | 38.00
Other | 25.00
Enclosure | 11.65
Total Project Cost | 195.25

## 9.2 Bill of Materials

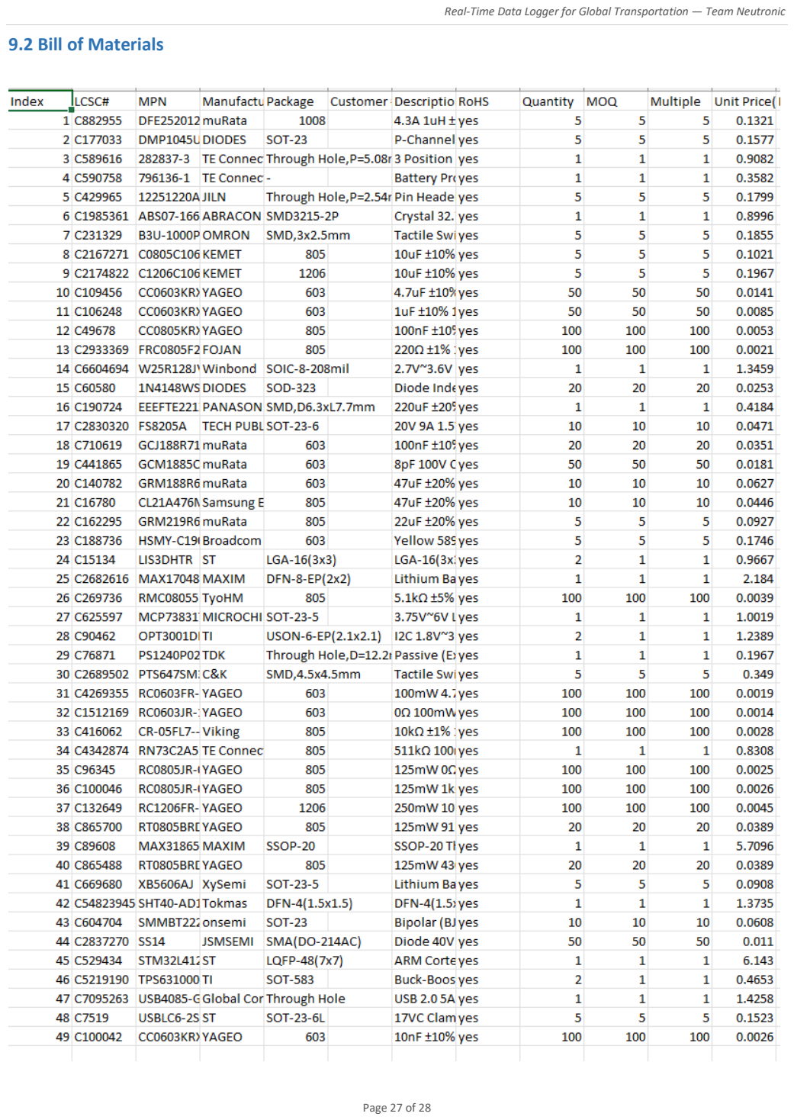
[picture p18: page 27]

## 9.3 Future Improvements

- Enable real-time location tracking by configuring the GNSS of the GSM module and updating the web dashboard to display package location.
- Upgrade to a higher energy-density battery for longer operational intervals.

•

## 10. Task Allocation

Team Member | Role / Domain | Work Done

230352K
Kumara K.B.R

Team Lead
Hardware Lead

System Architecture Design
Component Selection/BOM Optimization
PCB Schematic Design
PCB Layout Design
Component Soldering/Testing/Hardware Validation UI Design
Documentation

230353N
Kumara P.K.M.P

Mechanical Design Lead

Enclosure Design
UI Design
Problem Validation
GSM Module testing
Hardware Assembly

230527 D
Ranawaka R.A.G.K

Firmware/Software Lead

Firmware Design
Sensor Integration
PCB Schematic Design
GSM Module Testing
Problem Validation
PCB Testing

230300C
Jayaweera N.S

Web Design/
Cloud upload

Website Design
WebServer Integration
GSM Module testing
Documentation

230203G
Gunarathna K.T.M.B

Debugging, Mechanical Design

Problem identification
Enclosure Design
Documentation
Hardware Assembly

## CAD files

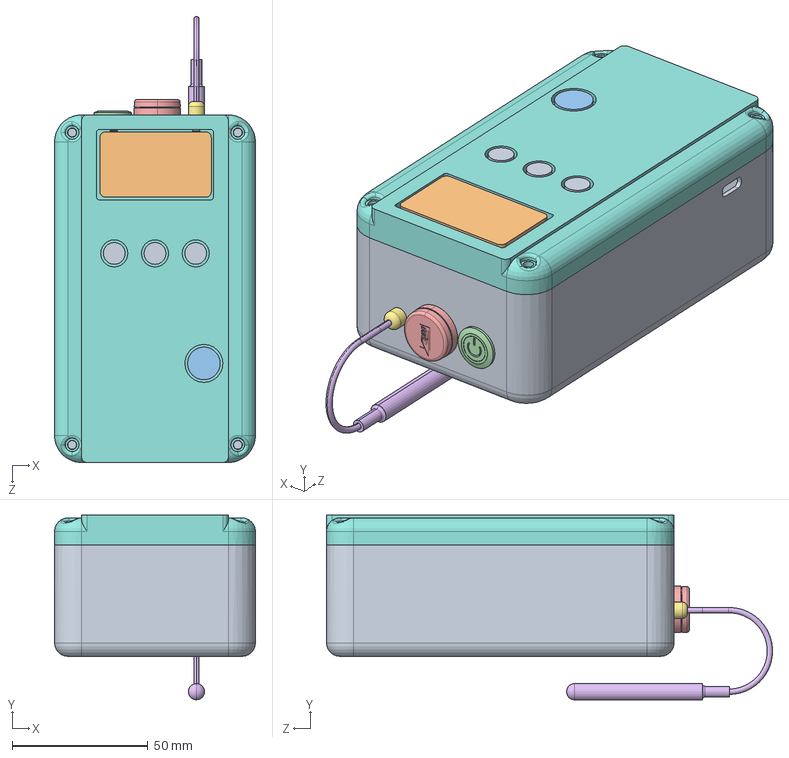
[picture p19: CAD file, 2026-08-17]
Enclosure Design/Assembly/Assem2.SLDASM
74.0 x 68.0 x 164.2 mm
EDR_box_final
boostpart
18650 Battery Holdernew.step
12mm Power Button With LED v1.step
event gore PMF100320.step
temp.step
rubber_bush
EDR_lid_final
switch_part_EDR x 3
acrylic_display
amb_light_acrylic

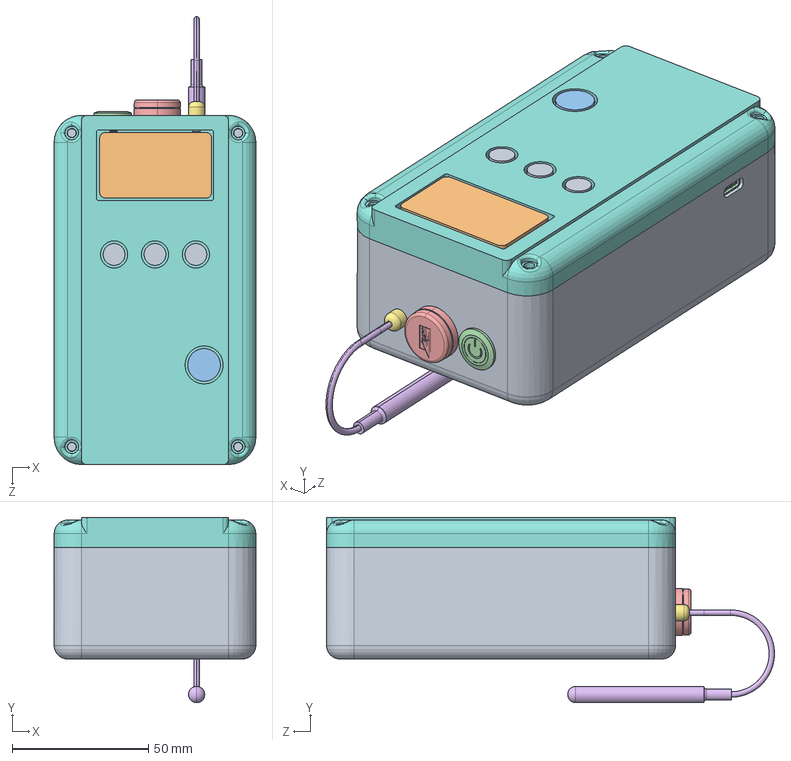
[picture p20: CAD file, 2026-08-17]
Enclosure Design/Assembly/Assem2_withpcb.SLDASM
74.0 x 68.0 x 164.2 mm
EDR_box_final
boostpart
18650 Battery Holdernew.step
12mm Power Button With LED v1.step
event gore PMF100320.step
temp.step
rubber_bush
EDR_lid_final
switch_part_EDR x 3
acrylic_display
amb_light_acrylic
Cold_chain_Logger_new_ed.step

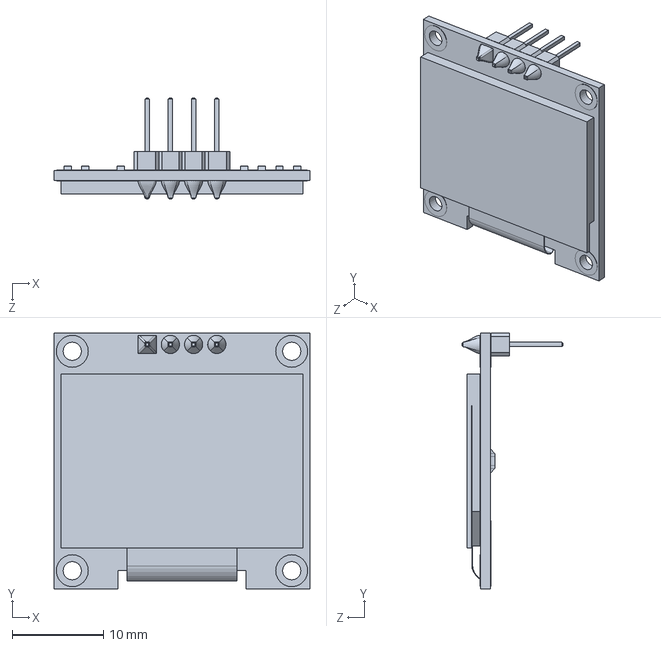
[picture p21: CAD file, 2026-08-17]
Enclosure Design/Assembly/0.96 OLED v3.step.SLDPRT
28.0 x 28.0 x 11.0 mm

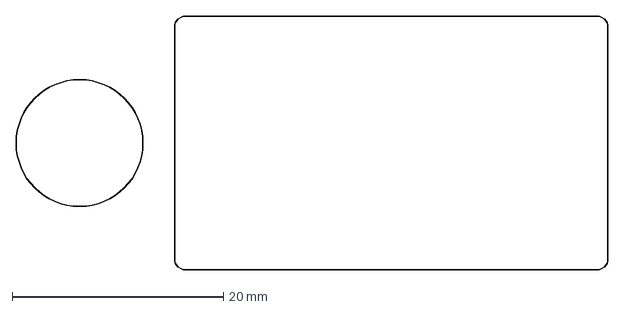
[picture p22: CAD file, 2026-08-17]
Enclosure Design/dxf_files/Acrylic_cut.DXF
56.0 x 24.0 mm

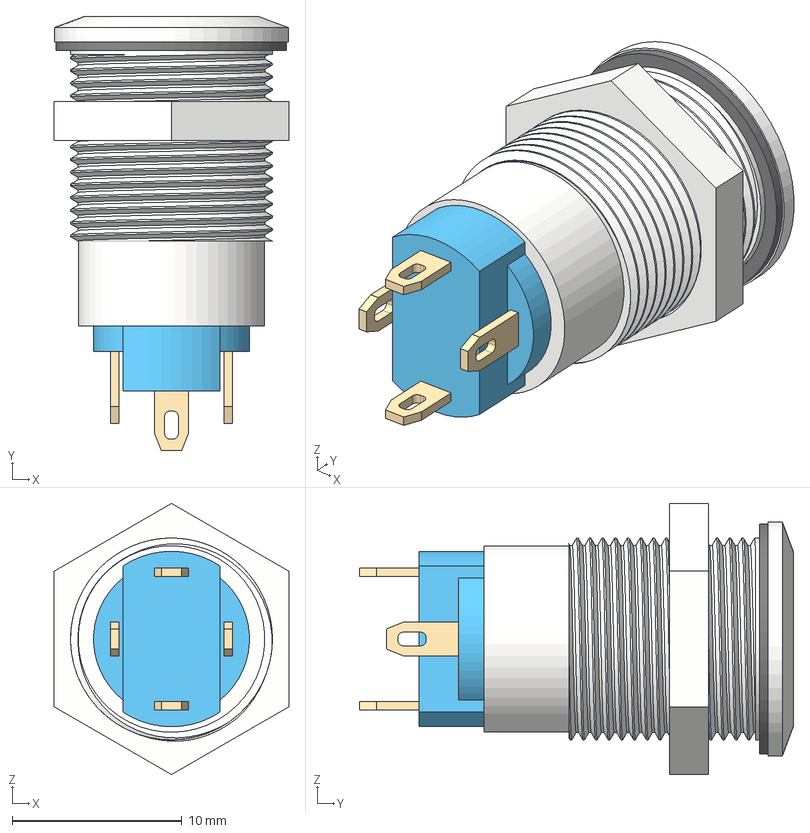
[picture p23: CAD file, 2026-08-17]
Enclosure Design/part_files/12mm Power Button With LED v1.step
13.8 x 25.6 x 16.0 mm

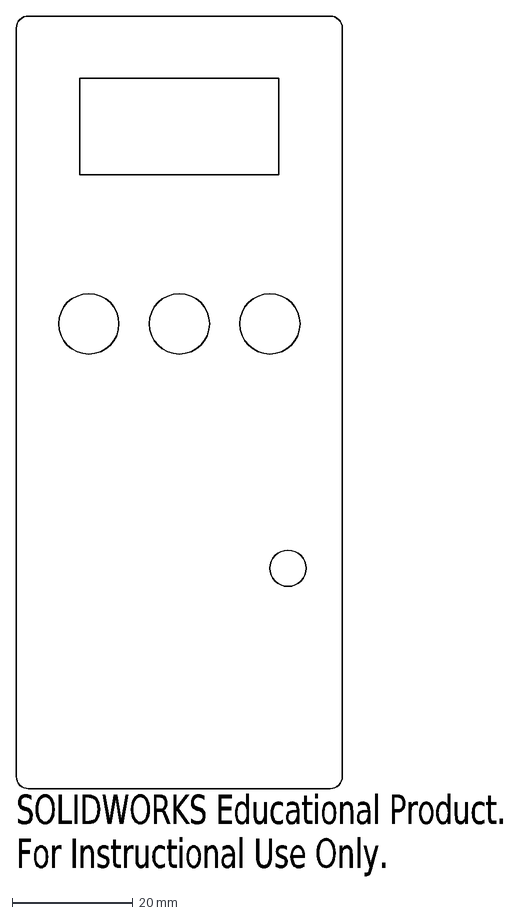
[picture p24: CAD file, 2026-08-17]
Enclosure Design/dxf_files/Test_sticker.DXF
SOLIDWORKS Educational Product.
For Instructional Use Only.

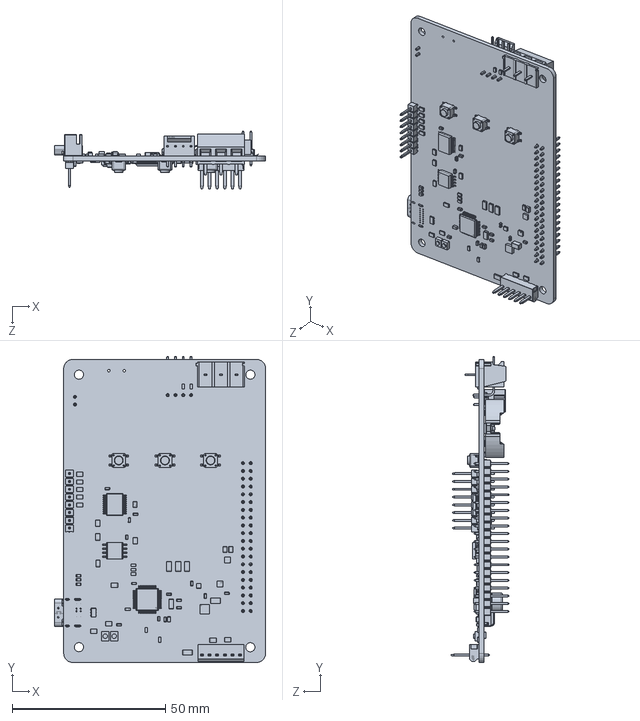
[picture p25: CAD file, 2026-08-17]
Enclosure Design/part_files/Cold_chain_Logger_new_ed.step.SLDPRT
69.0 x 99.9 x 19.0 mm

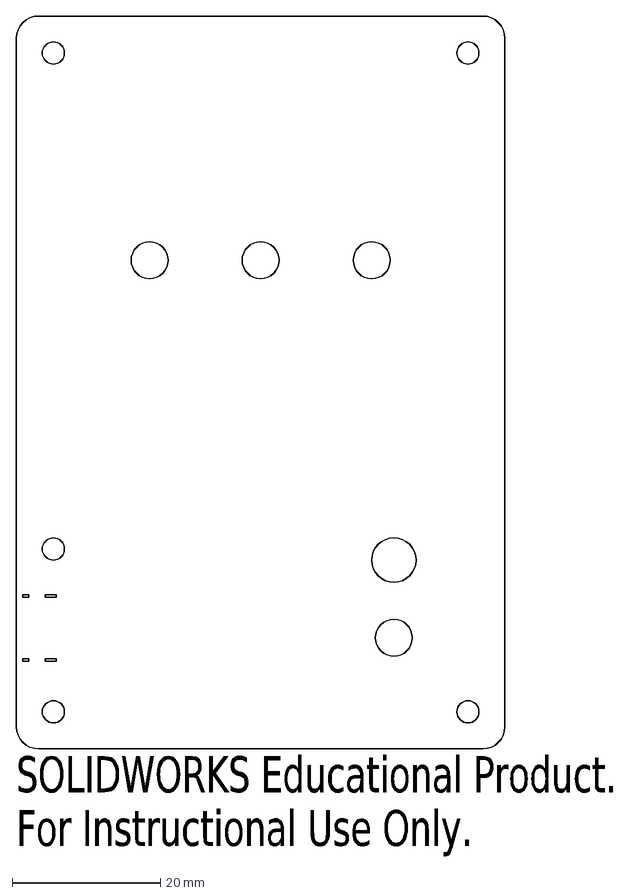
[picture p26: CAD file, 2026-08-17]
Enclosure Design/dxf_files/PCB_test_final.DXF
SOLIDWORKS Educational Product.
For Instructional Use Only.

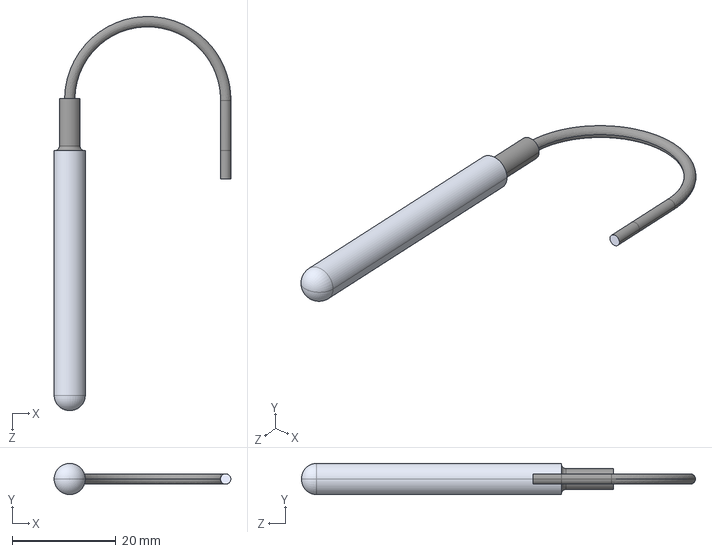
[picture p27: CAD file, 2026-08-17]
Enclosure Design/part_files/temp.STEP
34.0 x 6.00 x 75.8 mm

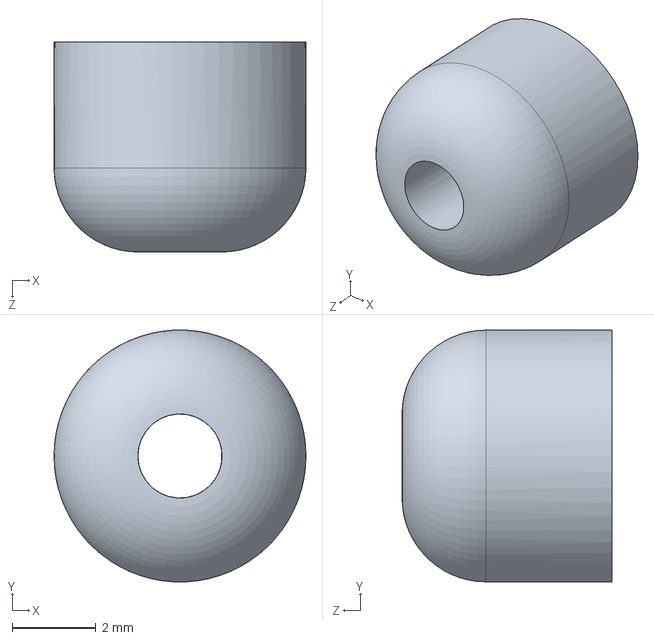
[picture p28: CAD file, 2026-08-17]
Enclosure Design/part_files/rubber_bush.SLDPRT
6.00 x 5.99 x 5.00 mm

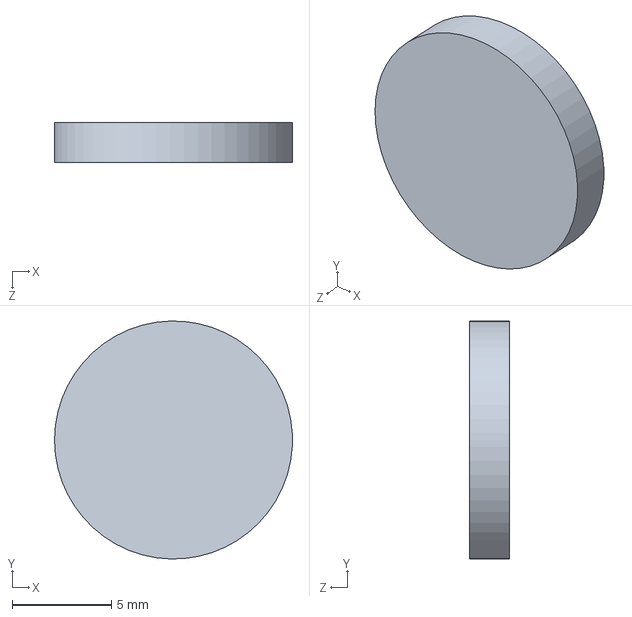
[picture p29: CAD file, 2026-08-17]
Enclosure Design/part_files/amb_light_acrylic.SLDPRT
12.0 x 12.0 x 2.00 mm

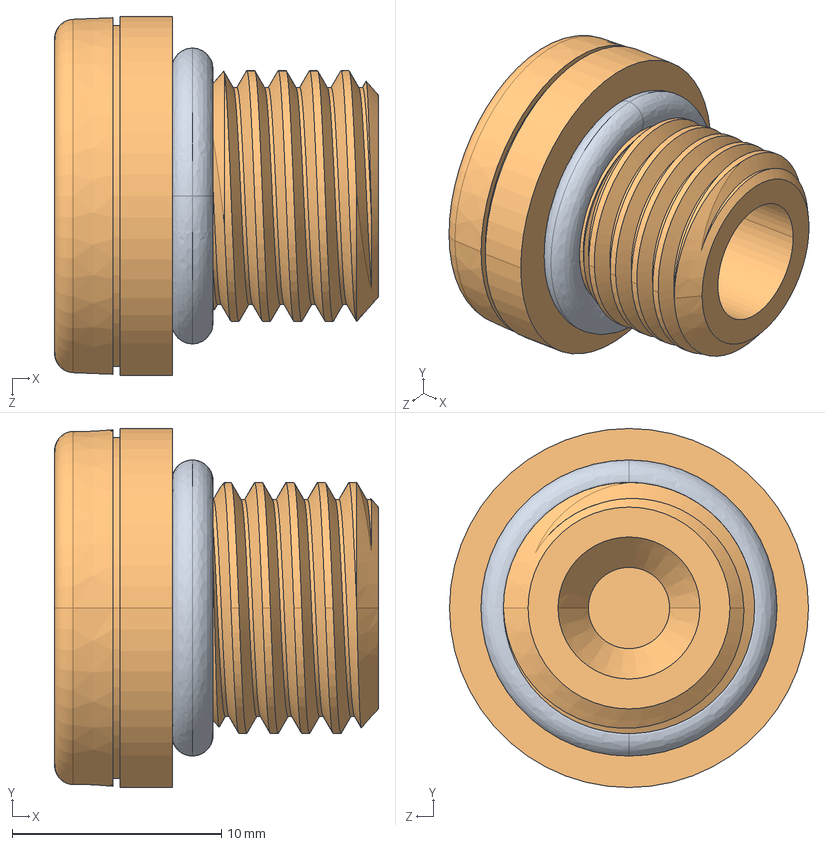
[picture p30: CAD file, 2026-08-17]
Enclosure Design/part_files/event gore PMF100320.STEP
15.5 x 17.1 x 17.1 mm

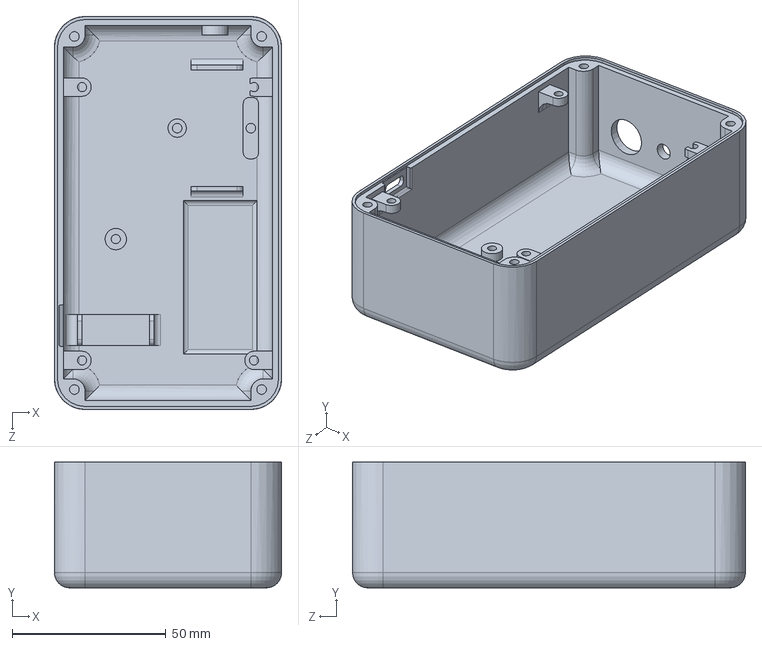
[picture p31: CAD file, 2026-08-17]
Enclosure Design/part_files/EDR_box_final.SLDPRT
74.0 x 41.0 x 128.0 mm

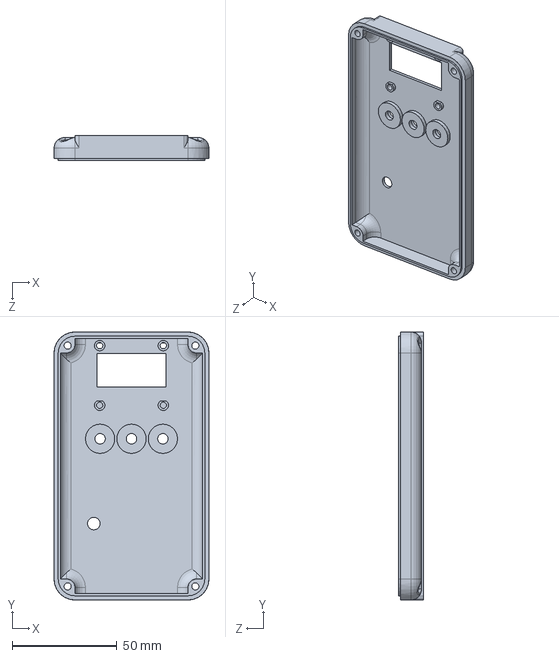
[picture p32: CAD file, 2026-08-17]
Enclosure Design/part_files/EDR_lid_final.SLDPRT
74.0 x 128.0 x 12.0 mm

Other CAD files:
Enclosure Design/part_files/Assem2.SLDASM
Hardware Design/Project_Outputs/Cold_chain_Logger.DWG
Enclosure Design/part_files/event gore PMF100320.step.SLDPRT
Enclosure Design/part_files/12mm Power Button With LED v1.step.SLDPRT
Enclosure Design/part_files/18650 Battery Holdernew.step.SLDPRT
Enclosure Design/part_files/Part2.SLDPRT
Enclosure Design/part_files/acrylic_display.SLDPRT
Enclosure Design/part_files/boostpart.SLDPRT
Enclosure Design/part_files/switch_part_EDR.SLDPRT
Enclosure Design/part_files/temp.step.SLDPRT

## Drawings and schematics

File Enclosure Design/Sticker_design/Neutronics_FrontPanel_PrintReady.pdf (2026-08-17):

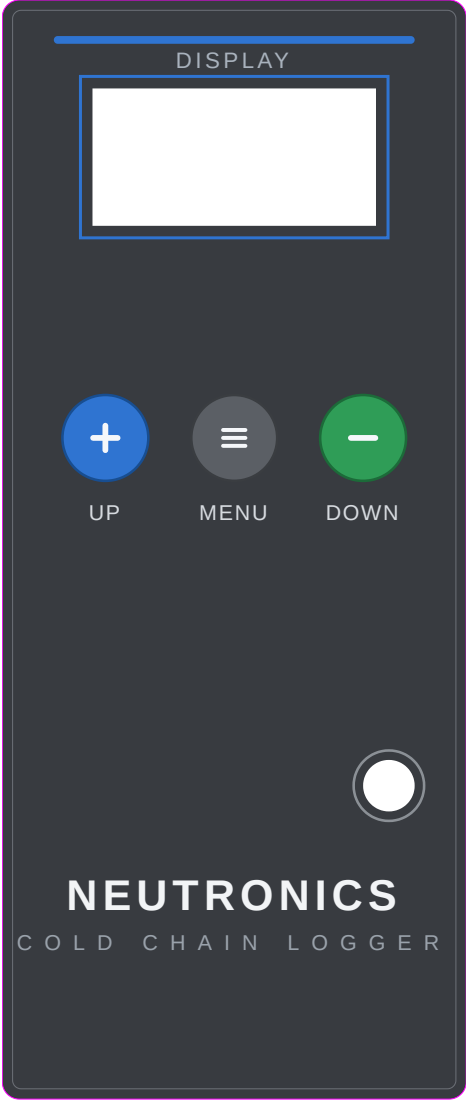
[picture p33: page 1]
D ISPLAY; MENU; DOWN; NEUTRONICS

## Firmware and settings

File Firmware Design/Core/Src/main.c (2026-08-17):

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
/* Includes ------------------------------------------------------------------*/
#include "main.h"
#include "fatfs.h"
#include "stm32l4xx_hal.h"
#include "usb_device.h"

/* USER CODE BEGIN Includes */
#include "Sensors.h"
#include "ssd1306.h"
#include "ssd1306_fonts.h"
#include <stdio.h>
#include <string.h>
#include "usbd_core.h"
#include "GSM.h"
extern USBD_HandleTypeDef hUsbDeviceFS;
/* USER CODE END Includes */

/* USER CODE BEGIN PTD */
// SPI Command to read the chip's ID
#define W25_CMD_JEDEC_ID 0x9F
// SPI Command to read standard data
#define W25_CMD_READ 0x03
#define W25_CMD_WRITE_ENABLE 0x06
#define W25_CMD_READ_STATUS  0x05
#define W25_CMD_SECTOR_ERASE 0x20
#define W25_CMD_PAGE_PROGRAM 0x02

#define W25_CS_LOW()  HAL_GPIO_WritePin(Storage_CS_GPIO_Port, Storage_CS_Pin, GPIO_PIN_RESET)
#define W25_CS_HIGH() HAL_GPIO_WritePin(Storage_CS_GPIO_Port, Storage_CS_Pin, GPIO_PIN_SET)

#define MAX_BUFFERED_READINGS 100 // Adjust based on your available RAM
typedef struct {
    uint8_t year;
    uint8_t month;
    uint8_t date;
    uint8_t hours;
    uint8_t minutes;
    uint8_t seconds;
    float temperature;
    float humidity;
    int16_t accel_x;
    int16_t accel_y;
    int16_t accel_z;
    uint8_t shock_event; // NEW FIELD
} SensorRecord_t;
/* USER CODE END PTD */

I2C_HandleTypeDef hi2c1;
I2C_HandleTypeDef hi2c2;

RTC_HandleTypeDef hrtc;

SPI_HandleTypeDef hspi1;

UART_HandleTypeDef huart1;

/* USER CODE BEGIN PV */
// Array to store the 3 bytes the chip sends back
uint8_t flash_id[3];
uint8_t test_read_buffer[10]; // Buffer to hold our read test
float check = 0.0f; // Variable to hold the floating-point value to be written to the CSV file
float debug=0.0f; 
float f_c= 0.0f;
uint32_t dif_time=0; 

FATFS fs;           // The File System Object
FIL fil;            // The File Object
UINT bytesWritten;  // Counter for bytes written

char log_buffer[128];

SensorRecord_t local_record_buffer[MAX_BUFFERED_READINGS];
uint32_t local_record_count = 0; // Tracks how many readings we have stored
volatile uint8_t shock_event_data = 0;

//Display variables
// ==========================================
// UI GLOBAL VARIABLES
// ==========================================
int Logging_interval = 30;// Logging interval in seconds (10-40)
int Uploading_Interval = 120;// Uploading interval in seconds (0-255)
int alarm_enable = 1;

int battery_percent = 73;           // Battery percentage (0-100)
char time_str[16] = "00:00:00";     // String to hold RTC time for OLED

typedef enum {
    UI_STATE_HOME,    // Main dashboard display
    UI_STATE_MENU,    // Scrolling through settings list
    UI_STATE_EDIT     // Tweaking a specific setting
} UI_State_t;

typedef struct {
    const char* label;   // Text to display on OLED
    int* target_var;     // Pointer to the actual global variable
    int min_val;         // Lower limit
    int max_val;         // Upper limit
    int step;            // Amount to change per click
} MenuItem_t;

UI_State_t current_state = UI_STATE_HOME;
int current_menu_index = 0;
uint8_t ui_needs_update = 1; 

#define DISPLAY_TIMEOUT_MS 60000U
uint8_t display_enabled = 1;
uint32_t last_user_activity_ms = 0;
uint32_t last_sensor_read_ms = 0; // Timer for our non-blocking 500ms loop
uint32_t last_upload_ms = 0;

MenuItem_t menu_items[] = {
    // Label                 Pointer               Min   Max    Step
    {"Logging Interval",    &Logging_interval,     10,   180,   10},  // Range: 10s to 120s (Step by 10s)
    {"Uploading Interval",  &Uploading_Interval,   60,   3600,  60},  // Range: 60s to 3600s (Step by 1 minute)
    {"Alarm Switch",        &alarm_enable,         0,    1,     1}  
};
const int TOTAL_MENU_ITEMS = sizeof(menu_items) / sizeof(MenuItem_t);
/* USER CODE END PV */

void SystemClock_Config(void);
static void MX_GPIO_Init(void);
static void MX_I2C1_Init(void);
static void MX_I2C2_Init(void);
static void MX_RTC_Init(void);
static void MX_SPI1_Init(void);
static void MX_USART1_UART_Init(void);
/* USER CODE BEGIN PFP */
void SPI_Set_Mode_Flash(void);
void SPI_Set_Mode_MAX31865(void);
void W25_Read_ID(void);
void W25_Read_Data(uint32_t address, uint8_t* buffer, uint32_t length);
void W25_Wait_For_Ready(void);
void W25_Write_Enable(void);
void W25_Erase_Sector(uint32_t address);
void W25_Write_Page(uint32_t address, uint8_t* buffer, uint16_t length);
void Update_Dashboard(void);
uint8_t Process_UI(void);
void Display_HomeScreen(void);
void Display_MenuScreen(void);
void Display_EditScreen(void);
/* USER CODE END PFP */

/* USER CODE BEGIN 0 */
// Shifts the SPI bus into Mode 0 for the Memory Chip
void SPI_Set_Mode_Flash(void)
{
// 1. Force the PT100 CS HIGH so it ignores the bus change
  HAL_GPIO_WritePin(MAX_CS_GPIO_Port, MAX_CS_Pin, GPIO_PIN_SET);
    
  // 2. Safely disable the SPI hardware block without breaking GPIOs
  __HAL_SPI_DISABLE(&hspi1);
    
  // 3. Fully restore ALL SPI parameters for Mode 0
  hspi1.Init.Mode = SPI_MODE_MASTER;
  hspi1.Init.Direction = SPI_DIRECTION_2LINES;
  hspi1.Init.DataSize = SPI_DATASIZE_8BIT;
  hspi1.Init.CLKPolarity = SPI_POLARITY_LOW;         // Mode 0
  hspi1.Init.CLKPhase = SPI_PHASE_1EDGE;             // Mode 0
  hspi1.Init.NSS = SPI_NSS_SOFT;
  hspi1.Init.BaudRatePrescaler = SPI_BAUDRATEPRESCALER_16; // Overwrite FatFs changes
  hspi1.Init.FirstBit = SPI_FIRSTBIT_MSB;
  hspi1.Init.TIMode = SPI_TIMODE_DISABLE;
  hspi1.Init.CRCCalculation = SPI_CRCCALCULATION_DISABLE;
  hspi1.Init.CRCPolynomial = 7;
  hspi1.Init.CRCLength = SPI_CRC_LENGTH_DATASIZE;
  hspi1.Init.NSSPMode = SPI_NSS_PULSE_DISABLE;

  HAL_SPI_Init(&hspi1);
}

// Shifts the SPI bus into Mode 3 for the PT100 Sensor
void SPI_Set_Mode_MAX31865(void)
{
// 1. Force the Flash CS HIGH so it ignores the bus change
  HAL_GPIO_WritePin(Storage_CS_GPIO_Port, Storage_CS_Pin, GPIO_PIN_SET);
    
  // 2. Safely disable the SPI hardware block without breaking GPIOs
  __HAL_SPI_DISABLE(&hspi1);
    
  // 3. Fully restore ALL SPI parameters for Mode 3
  hspi1.Init.Mode = SPI_MODE_MASTER;
  hspi1.Init.Direction = SPI_DIRECTION_2LINES;
  hspi1.Init.DataSize = SPI_DATASIZE_8BIT;
  hspi1.Init.CLKPolarity = SPI_POLARITY_HIGH;        // Mode 3
  hspi1.Init.CLKPhase = SPI_PHASE_2EDGE;             // Mode 3
  hspi1.Init.NSS = SPI_NSS_SOFT;
  hspi1.Init.BaudRatePrescaler = SPI_BAUDRATEPRESCALER_16; // Guarantee safe clock speed!
  hspi1.Init.FirstBit = SPI_FIRSTBIT_MSB;
  hspi1.Init.TIMode = SPI_TIMODE_DISABLE;
  hspi1.Init.CRCCalculation = SPI_CRCCALCULATION_DISABLE;
  hspi1.Init.CRCPolynomial = 7;
  hspi1.Init.CRCLength = SPI_CRC_LENGTH_DATASIZE;
  hspi1.Init.NSSPMode = SPI_NSS_PULSE_DISABLE;

  HAL_SPI_Init(&hspi1);
}
void W25_Read_ID(void)
{
  SPI_Set_Mode_Flash(); // Ensure SPI is in Mode 0 for the flash chip

  uint8_t cmd = W25_CMD_JEDEC_ID;
    
  // 1. Pull CS Low to wake up the memory chip
  W25_CS_LOW();
    
  // 2. Transmit the 0x9F command over MOSI
  HAL_SPI_Transmit(&hspi1, &cmd, 1, 100);
    
  // 3. Receive the 3-byte response over MISO
  HAL_SPI_Receive(&hspi1, flash_id, 3, 100);
    
  // 4. Pull CS High to put the chip back to sleep
  W25_CS_HIGH();
}

void W25_Read_Data(uint32_t address, uint8_t* buffer, uint32_t length)
{
    SPI_Set_Mode_Flash(); // Ensure SPI is in Mode 0 for the flash chip
    uint8_t spi_data[4];

    // 1. Setup the command and 24-bit address (MSB first)
    spi_data[0] = W25_CMD_READ;                 // Instruction
    spi_data[1] = (address >> 16) & 0xFF;       // Address High Byte
    spi_data[2] = (address >> 8)  & 0xFF;       // Address Middle Byte
    spi_data[3] = (address & 0xFF);             // Address Low Byte

    // 2. Pull CS Low to select the chip
    W25_CS_LOW();

    // 3. Send the Command and Address (4 bytes total)
    HAL_SPI_Transmit(&hspi1, spi_data, 4, 100);

    // 4. Read the requested data directly into the buffer
    HAL_SPI_Receive(&hspi1, buffer, length, 1000);

    // 5. Pull CS High to put the chip back to sleep
    W25_CS_HIGH();
}

// Checks the BUSY bit in the status register and waits until it clears
void W25_Wait_For_Ready(void)
{
    SPI_Set_Mode_Flash(); // Ensure SPI is in Mode 0 for the flash chip
    uint8_t cmd = W25_CMD_READ_STATUS;
    uint8_t status = 0;
    
    W25_CS_LOW();
    HAL_SPI_Transmit(&hspi1, &cmd, 1, 100);
    do {
        // Keep reading the status register until bit 0 (BUSY) becomes 0
        HAL_SPI_Receive(&hspi1, &status, 1, 100);
    } while ((status & 0x01) == 0x01); 
    W25_CS_HIGH();
}

// Unlocks the memory to allow a write or erase
void W25_Write_Enable(void)
{
    SPI_Set_Mode_Flash(); // Ensure SPI is in Mode 0 for the flash chip
    uint8_t cmd = W25_CMD_WRITE_ENABLE;
    W25_CS_LOW();
    HAL_SPI_Transmit(&hspi1, &cmd, 1, 100);
    W25_CS_HIGH();
}

// Wipes a 4096-byte chunk of memory clean to 0xFF
void W25_Erase_Sector(uint32_t address)
{
    SPI_Set_Mode_Flash(); // Ensure SPI is in Mode 0 for the flash chip
    uint8_t spi_data[4];
    
    W25_Write_Enable(); // MUST unlock before erasing
    
    spi_data[0] = W25_CMD_SECTOR_ERASE;
    spi_data[1] = (address >> 16) & 0xFF;
    spi_data[2] = (address >> 8)  & 0xFF;
    spi_data[3] = (address & 0xFF);
    
    W25_CS_LOW();
    HAL_SPI_Transmit(&hspi1, spi_data, 4, 100);
    W25_CS_HIGH();
    
    W25_Wait_For_Ready(); // Wait for the physical erase to finish
}

// Writes up to 256 bytes of data to an ERASED sector
void W25_Write_Page(uint32_t address, uint8_t* buffer, uint16_t length)
{
    SPI_Set_Mode_Flash(); // Ensure SPI is in Mode 0 for the flash chip
    uint8_t spi_data[4];
    
    W25_Write_Enable(); // MUST unlock before writing
    
    spi_data[0] = W25_CMD_PAGE_PROGRAM;
    spi_data[1] = (address >> 16) & 0xFF;
    spi_data[2] = (address >> 8)  & 0xFF;
    spi_data[3] = (address & 0xFF);
    
    W25_CS_LOW();
    HAL_SPI_Transmit(&hspi1, spi_data, 4, 100);       // Send Address
    HAL_SPI_Transmit(&hspi1, buffer, length, 1000);   // Send Data Array
    W25_CS_HIGH();
    
    W25_Wait_For_Ready(); // Wait for the physical write to finish
}

uint8_t Process_UI(void) {
    static uint8_t menu_was_pressed = 0;
    static uint8_t up_was_pressed = 0;
    static uint8_t down_was_pressed = 0;
    uint8_t changed = 0;

    uint8_t menu_pressed = (HAL_GPIO_ReadPin(Menu_GPIO_Port, Menu_Pin) == GPIO_PIN_RESET);
    uint8_t up_pressed   = (HAL_GPIO_ReadPin(User_DOWN_GPIO_Port, User_DOWN_Pin) == GPIO_PIN_RESET);
    uint8_t down_pressed = (HAL_GPIO_ReadPin(User_UP_GPIO_Port, User_UP_Pin) == GPIO_PIN_RESET);

    // MENU BUTTON LOGIC
    if (menu_pressed && !menu_was_pressed) { 
        menu_was_pressed = 1;
        changed = 1;
        if (current_state == UI_STATE_HOME) {
            current_state = UI_STATE_MENU;
            current_menu_index = 0; 
        } else if (current_state == UI_STATE_MENU) {
            current_state = UI_STATE_EDIT;
        } else if (current_state == UI_STATE_EDIT) {
            current_state = UI_STATE_MENU;
        }
    } else if (!menu_pressed) menu_was_pressed = 0; 

    // UP BUTTON LOGIC
    if (up_pressed && !up_was_pressed) {
        up_was_pressed = 1;
        changed = 1;
        if (current_state == UI_STATE_MENU) {
            current_menu_index--;
            if (current_menu_index < 0) current_menu_index = TOTAL_MENU_ITEMS - 1; 
        } else if (current_state == UI_STATE_EDIT) {
            MenuItem_t* active_item = &menu_items[current_menu_index];
            *(active_item->target_var) += active_item->step;
            if (*(active_item->target_var) > active_item->max_val) *(active_item->target_var) = active_item->max_val;
        } else if (current_state == UI_STATE_HOME) {
            current_state = UI_STATE_MENU;
            current_menu_index = 0;
        }
    } else if (!up_pressed) up_was_pressed = 0;

    // DOWN BUTTON LOGIC
    if (down_pressed && !down_was_pressed) {
        down_was_pressed = 1;
        changed = 1;
        if (current_state == UI_STATE_MENU) {
            current_menu_index++;
            if (current_menu_index >= TOTAL_MENU_ITEMS) {
                current_state = UI_STATE_HOME;
                current_menu_index = 0; 
            }
        } else if (current_state == UI_STATE_EDIT) {
            MenuItem_t* active_item = &menu_items[current_menu_index];
            *(active_item->target_var) -= active_item->step;
            if (*(active_item->target_var) < active_item->min_val) *(active_item->target_var) = active_item->min_val;
        } else if (current_state == UI_STATE_HOME) {
            current_state = UI_STATE_MENU;
            current_menu_index = 0;
        }
    } else if (!down_pressed) down_was_pressed = 0;

    return changed;
}

void Display_HomeScreen(void)
{
  char buf[32];
  ssd1306_Fill(Black);

  ssd1306_SetCursor(2, 0);
  ssd1306_WriteString((char*)"Temp", Font_6x8, White);

  // UPDATED TO USE YOUR PT100 VARIABLE
  snprintf(buf, sizeof(buf), "%.1fC", live_temperature);
  ssd1306_SetCursor(2, 10);
  ssd1306_WriteString(buf, Font_16x24, White);

  // UPDATED TO USE YOUR SHT45 VARIABLE
  snprintf(buf, sizeof(buf), "Hum: %.0f%%", humidity);
  ssd1306_SetCursor(64, 10);
  ssd1306_WriteString(buf, Font_7x10, White);

  snprintf(buf, sizeof(buf), "Bat: %d%%", battery_percent);
  ssd1306_SetCursor(64, 36);
  ssd1306_WriteString(buf, Font_7x10, White);

  ssd1306_SetCursor(2, 50);
  ssd1306_WriteString(time_str, Font_7x10, White);

  ssd1306_UpdateScreen();
}

void Display_MenuScreen(void)
{
  char buf[32];
  ssd1306_Fill(Black);
  ssd1306_SetCursor(2, 0);
  ssd1306_WriteString((char*)"SETTINGS", Font_7x10, White);
  ssd1306_Line(0, 12, 127, 12, White);

  int y_pos = 18;
  for (int i = 0; i < TOTAL_MENU_ITEMS; i++) {
    if (i == current_menu_index) {
      ssd1306_DrawRectangle(0, y_pos - 2, 127, y_pos + 10, White);
      ssd1306_SetCursor(4, y_pos);
      snprintf(buf, sizeof(buf), "%s: %d", menu_items[i].label, *(menu_items[i].target_var));
      ssd1306_WriteString(buf, Font_6x8, Black); 
    } else {
      ssd1306_SetCursor(4, y_pos);
      snprintf(buf, sizeof(buf), "%s: %d", menu_items[i].label, *(menu_items[i].target_var));
      ssd1306_WriteString(buf, Font_6x8, White);
    }
    y_pos += 14;
  }
  ssd1306_SetCursor(2, 54);
  ssd1306_WriteString((char*)"Menu:Select  Dn:Back", Font_6x8, White);
  ssd1306_UpdateScreen();
}

void Display_EditScreen(void)
{
  char buf[32];
  ssd1306_Fill(Black);
  MenuItem_t* active_item = &menu_items[current_menu_index];

  ssd1306_SetCursor(2, 0);
  ssd1306_WriteString((char*)"EDIT MODE", Font_7x10, White);
  ssd1306_Line(0, 12, 127, 12, White);

  ssd1306_SetCursor(2, 18);
  ssd1306_WriteString((char*)active_item->label, Font_11x18, White);

  snprintf(buf, sizeof(buf), "%d", *(active_item->target_var));
  ssd1306_SetCursor(2, 40);
  ssd1306_WriteString(buf, Font_16x24, White);

  snprintf(buf, sizeof(buf), "Range: %d-%d  Menu:Back", active_item->min_val, active_item->max_val);
  ssd1306_SetCursor(2, 54);
  ssd1306_WriteString(buf, Font_6x8, White);
  ssd1306_UpdateScreen();
}
/* USER CODE END 0 */
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

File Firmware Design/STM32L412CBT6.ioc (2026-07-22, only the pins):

Mcu.UserName=STM32L412CBTx
PA10.Signal=USART1_RX
PA11.Signal=USB_DM
PA12.Signal=USB_DP
PA4.GPIO_Label=Storage_CS
PA4.Signal=GPIO_Output
PA5.Signal=SPI1_SCK
PA6.Signal=SPI1_MISO
PA7.Signal=SPI1_MOSI
PA8.GPIO_Label=MAX_CS
PA8.Signal=GPIO_Output
PA9.Signal=USART1_TX
PB0.GPIO_Label=Temp_int
PB0.Signal=GPXTI0
PB1.GPIO_Label=IMU_int
PB1.Signal=GPXTI1
PB10.Signal=I2C2_SCL
PB11.Signal=I2C2_SDA
PB14.GPIO_Label=User_UP
PB14.Signal=GPXTI14
PB15.GPIO_Label=User_DOWN
PB15.Signal=GPXTI15
PB2.GPIO_Label=Light_int
PB2.Signal=GPXTI2
PB6.Signal=I2C1_SCL
PB7.Signal=I2C1_SDA
PB9.GPIO_Label=Menu
PB9.Signal=GPXTI9

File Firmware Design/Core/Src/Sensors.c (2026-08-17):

#include "Sensors.h"
#include <stdint.h>
#include <math.h>


#define RREF                430.0f  // 400 Ohm reference resistor for PT100[cite: 1]
#define RTD_A               3.90830e-3f
#define RTD_B               -5.77500e-7f
#define R_0                 100.0f   // Resistance of PT100 at 0°C

// MAX31865 Register Addresses
#define REG_CONFIG_READ     0x00
#define REG_CONFIG_WRITE    0x80
#define REG_RTD_MSB         0x01
#define REG_FAULT_STATUS    0x07

// Configuration register bitmasks
#define CONFIG_VBIAS        0x80  // D7: 1 = Bias ON
#define CONFIG_1SHOT        0x20  // D5: 1 = 1-shot conversion
#define CONFIG_3WIRE        0x10  // D4: 1 = 3-wire config
#define CONFIG_FAULT_CLR    0x02  // D1: 1 = Clear fault status
#define CONFIG_50HZ         0x01  // D0: 1 = 50Hz filter

#define MAX_CS_LOW()  HAL_GPIO_WritePin(MAX_CS_GPIO_Port, MAX_CS_Pin, GPIO_PIN_RESET)
#define MAX_CS_HIGH() HAL_GPIO_WritePin(MAX_CS_GPIO_Port, MAX_CS_Pin, GPIO_PIN_SET)


//SHT45
#define SHT45_ADDR (0x44 << 1) // 0x88
// LIS3DHTR
#define LIS3DH_ADDR (0x18 << 1) // 0x30


volatile float live_temperature = 0.0f;
volatile uint16_t raw_rtd_code = 0;
volatile float R_rtd = 0.0f;
volatile uint8_t fault_register = 0;
float temp = 0.0f; // Optional: Variable to hold calculated temperature
float dummy = 0.0f; // Optional: Dummy variable to indicate valid temperature reading

//SHT45 Variable to hold the calculated temperature and humidity
float temperature = 0.0f;
float humidity = 0.0f;

// LIS3DHTR Variables to hold the X, Y, Z axis readings
int16_t LIS3DH_X = 0;
int16_t LIS3DH_Y = 0;
int16_t LIS3DH_Z = 0;

// Shifts the SPI bus into Mode 3 for the PT100 Sensor
static void SPI_Set_Mode_MAX31865(void)
{
  // 1. Force the Flash CS HIGH so it ignores the bus change
  HAL_GPIO_WritePin(Storage_CS_GPIO_Port, Storage_CS_Pin, GPIO_PIN_SET);
    
  // 2. Completely reset the SPI peripheral to clear locks and errors
  HAL_SPI_DeInit(&hspi1);
    
  // 3. Apply Mode 3 settings
  hspi1.Init.CLKPolarity = SPI_POLARITY_HIGH;
  hspi1.Init.CLKPhase = SPI_PHASE_2EDGE;
  HAL_SPI_Init(&hspi1);
}

void MAX31865_Init(void)
{
  SPI_Set_Mode_MAX31865(); // Ensure SPI is in Mode 3 for the MAX31865
  // Set the configuration register to enable VBIAS, 3-wire mode, and 50Hz filter
  // 1. Turn VBIAS ON, set 3-wire mode, and configure the 50Hz filter
  uint8_t config = CONFIG_VBIAS | CONFIG_3WIRE | CONFIG_50HZ;
  MAX31865_WriteRegister(REG_CONFIG_WRITE, config);
  
}

void MAX31865_WriteRegister(uint8_t reg, uint8_t value)
{
  SPI_Set_Mode_MAX31865(); // Ensure SPI is in Mode 3 for the MAX31865
  uint8_t data[2] = { reg, value };
  MAX_CS_LOW();
  HAL_SPI_Transmit(&hspi1, data, 2, HAL_MAX_DELAY);
  MAX_CS_HIGH();
}

uint8_t MAX31865_ReadRegister(uint8_t reg)
{
  SPI_Set_Mode_MAX31865(); // Ensure SPI is in Mode 3 for the MAX31865
  uint8_t tx_data[2] = { reg, 0x00 };
  uint8_t rx_data[2] = { 0 };
  
  MAX_CS_LOW();
  HAL_SPI_TransmitReceive(&hspi1, tx_data, rx_data, 2, HAL_MAX_DELAY);
  MAX_CS_HIGH();
  
  return rx_data[1];
}

void MAX31865_ReadRTD(void)
{
  SPI_Set_Mode_MAX31865(); // Ensure SPI is in Mode 3 for the MAX31865
  dummy = 9.0f; // Optional: Reset dummy variable at the start of the function
  uint8_t tx_data[3] = { REG_RTD_MSB, 0x00, 0x00 };
  uint8_t rx_data[3] = { 0 };
  
  // 1. Recreate the base configuration (VBIAS ON, 3-Wire, 50Hz)
  uint8_t config = CONFIG_VBIAS | CONFIG_3WIRE | CONFIG_50HZ;
  // 2. Wait for the input filter capacitors to charge (~10.5 RC constants + 1ms)
  HAL_Delay(15); 
  
  // 3. Trigger 1-Shot conversion by adding the 1-SHOT bit
  config |= CONFIG_1SHOT;
  MAX31865_WriteRegister(REG_CONFIG_WRITE, config);
  dummy = 9.1f; // Optional: Set a dummy variable to indicate that the 1-shot conversion has been triggered
  // 4. Wait for conversion to complete (~62.5ms for 50Hz single conversion)
  HAL_Delay(65); 

  // 5. Read the 2 RTD data bytes sequentially
  MAX_CS_LOW();
  HAL_SPI_TransmitReceive(&hspi1, tx_data, rx_data, 3, HAL_MAX_DELAY);
  MAX_CS_HIGH();
  dummy = 9.2f; // Optional: Set a dummy variable to indicate that the RTD data has been read
  // 6. Instantly shut off VBIAS to save power
  MAX31865_WriteRegister(REG_CONFIG_WRITE, CONFIG_3WIRE | CONFIG_50HZ);
  
  // 7. Process Data
  uint16_t rtd_raw = (rx_data[1] << 8) | rx_data[2];
  dummy = 9.3f; // Optional: Set a dummy variable to indicate that the raw RTD data has been processed
  // Check if the Fault flag (D0 of LSB) is set[cite: 1]
  if (rtd_raw & 0x01) 
  {
    dummy= 3.0f; // Optional: Set a dummy variable to indicate fault condition
    fault_register = MAX31865_ReadRegister(REG_FAULT_STATUS); // Read fault register[cite: 1]
    MAX31865_WriteRegister(REG_CONFIG_WRITE, CONFIG_FAULT_CLR | CONFIG_3WIRE | CONFIG_50HZ); // Clear fault[cite: 1]
    return; // Skip calculation on active fault
  }
  
  raw_rtd_code = rtd_raw >> 1; // Shift out the fault status bit to get 15-bit ADC code[cite: 1]
  dummy = 9.4f; // Optional: Set a dummy variable to indicate that the raw RTD code has been extracted
  // 8. Calculate Resistance[cite: 1]
  R_rtd = ((float)raw_rtd_code * RREF) / 32768.0f; // R_rtd = (ADC_code * Rref) / 2^15[cite: 1]
  
  if (R_rtd >= 100.0f) 
  {
    dummy = 2.0f; // Optional: Set a dummy variable to indicate invalid resistance reading
    float Z1 = -RTD_A;
    float Z2 = RTD_A * RTD_A - 4.0f * RTD_B * (1.0f - (R_rtd / R_0));
    temp = (Z1 + sqrtf(Z2)) / (2.0f * RTD_B);

  } else if (R_rtd < 100.0f) 
  {
    temp = -242.02f 
            + (2.2228f * R_rtd) 
            + (2.5859e-3f * R_rtd * R_rtd) 
            + (4.8260e-6f * R_rtd * R_rtd * R_rtd) 
            - (2.8183e-8f * R_rtd * R_rtd * R_rtd * R_rtd);
  }

  
  // 10. Range validation check before mapping to the watch variable[cite: 1]
  if (temp >= -200.0f && temp <= 850.0f) 
  {
    live_temperature = temp;
    dummy = 1.0f; // Optional: Set a dummy variable to indicate valid temperature reading
  }
}

void SHT45_Read (void)
{
    uint8_t cmd = 0xFD; // High precision measurement command
    uint8_t data[6] = {0};

    if (HAL_I2C_Master_Transmit(&hi2c1, SHT45_ADDR, &cmd, 1, HAL_MAX_DELAY) == HAL_OK)
    {
        HAL_Delay(10); // Wait for measurement to complete (~max 8.3ms)
        
        // Read 6 bytes (2B Temp + 1B CRC + 2B Humidity + 1B CRC)
        if (HAL_I2C_Master_Receive(&hi2c1, SHT45_ADDR, data, 6, HAL_MAX_DELAY) == HAL_OK)
        {
            uint16_t t_ticks = (data[0] << 8) | data[1];
            uint16_t rh_ticks = (data[3] << 8) | data[4];

            // Formulas provided by Sensirion datasheet
            temperature = -45.0f + 175.0f * ((float)t_ticks / 65535.0f);
            humidity = -6.0f + 125.0f * ((float)rh_ticks / 65535.0f);
            if (humidity > 100.0f) humidity = 100.0f;
            if (humidity < 0.0f) humidity = 0.0f;
        }
    }
}
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

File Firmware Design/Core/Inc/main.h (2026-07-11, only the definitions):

#define Storage_CS_Pin GPIO_PIN_4
#define Storage_CS_GPIO_Port GPIOA
#define Temp_int_Pin GPIO_PIN_0
#define Temp_int_GPIO_Port GPIOB
#define IMU_int_Pin GPIO_PIN_1
#define IMU_int_GPIO_Port GPIOB
#define Light_int_Pin GPIO_PIN_2
#define Light_int_GPIO_Port GPIOB
#define User_UP_Pin GPIO_PIN_14
#define User_UP_GPIO_Port GPIOB
#define User_DOWN_Pin GPIO_PIN_15
#define User_DOWN_GPIO_Port GPIOB
#define MAX_CS_Pin GPIO_PIN_8
#define MAX_CS_GPIO_Port GPIOA
#define Menu_Pin GPIO_PIN_9
#define Menu_GPIO_Port GPIOB

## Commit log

2026-06-30 Initial commit: Add Altium project structure and files
    [Cloud Upload.SchDoc, Cold_chain_Logger.DWG, EDR Smart Cold Chain Logger.PrjPcb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]
2026-06-30 Add STM32L412CBT6 project
2026-07-04 STM32L412CBT6 Updated version
2026-07-04 Resolve merge conflict and update STM32 project files
    [main.c]
2026-07-11 Updated with Sensors+Memory
2026-07-11 Update Sensors, Memory and OLED
2026-07-21 Updated STM32L412CBT6 with GSM
2026-07-22 Crash fix
    [Cloud Upload.SchDoc, Cold_chain_Logger.DWG, Cold_chain_Logger.PcbDoc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]
2026-07-22 Initial setup
    [EDR Smart Cold Chain Logger.PrjPcb]
2026-08-17 Enclosure Desing and Report
    [0.96 OLED v3.step.SLDPRT, 12mm Power Button With LED v1.step, 12mm Power Button With LED v1.step.SLDPRT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]

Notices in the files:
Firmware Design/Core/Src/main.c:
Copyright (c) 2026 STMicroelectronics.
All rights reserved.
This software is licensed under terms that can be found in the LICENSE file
